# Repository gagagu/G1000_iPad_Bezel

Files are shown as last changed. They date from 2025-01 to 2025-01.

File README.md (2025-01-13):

# G1000_iPad_Bezel
G1000 iPad Bezel for Simionic &amp; Mobiflight

This is my DIY Garmin G100 Bezel made for using with my iPad. You can use it with the Simionic G1000 App or with Mobiflight and something like Spacedesk. It's not finished but working.
The ESP is used for emulating an bluetooth keyboard for controling the Simionic App. The Arduino is controlling the Encoders, Buttons and the ESP32. You can also remove the ESP32 and use the G1000 only with Mobiflight and an Screen App like Spacedesk.
The Bezel is 3d printed with an Prusa XL 

##I had some power issues with my design so i had to implement an level converter and split the power lines from ESP32, Arduino and the other electronics. This is not implemented in the Schematic and PCB, yet.

## The design has some issues but with some knowledge in electronics you could get it to work. This is nothing for a beginner in electronics!

# Additional Files:

G1000 Pan Zoom switch by FlightSimMaker on Thingiverse: 
(https://www.thingiverse.com/thing:4222606

G1000 Knobs and Dual Rotary Encoder by FlightSimMaker on Thingiverse: 
(https://www.thingiverse.com/thing:4373531]

## Discord
You are welcome to join my Discord to get Info and support, [here](https://discord.gg/zrYUcJWu7F)

# Gallery

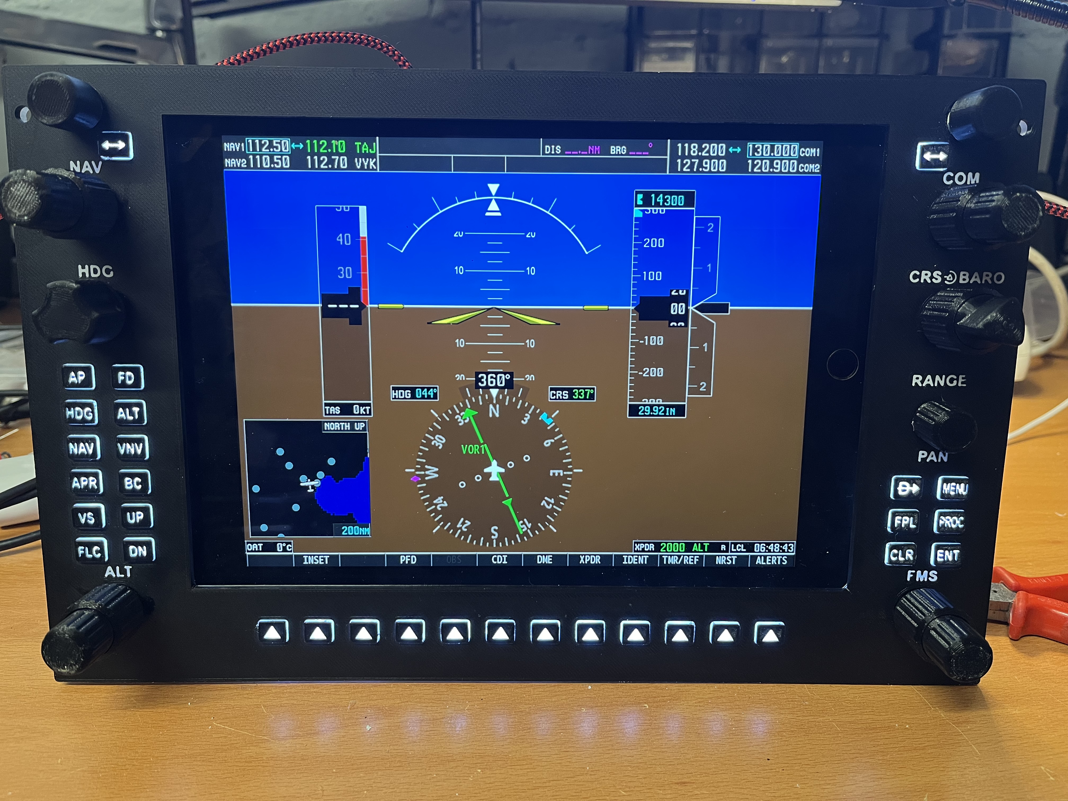
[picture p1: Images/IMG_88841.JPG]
[](https://github.com/gagagu/G1000_iPad_Bezel/blob/main/Images/IMG_88841.JPG)
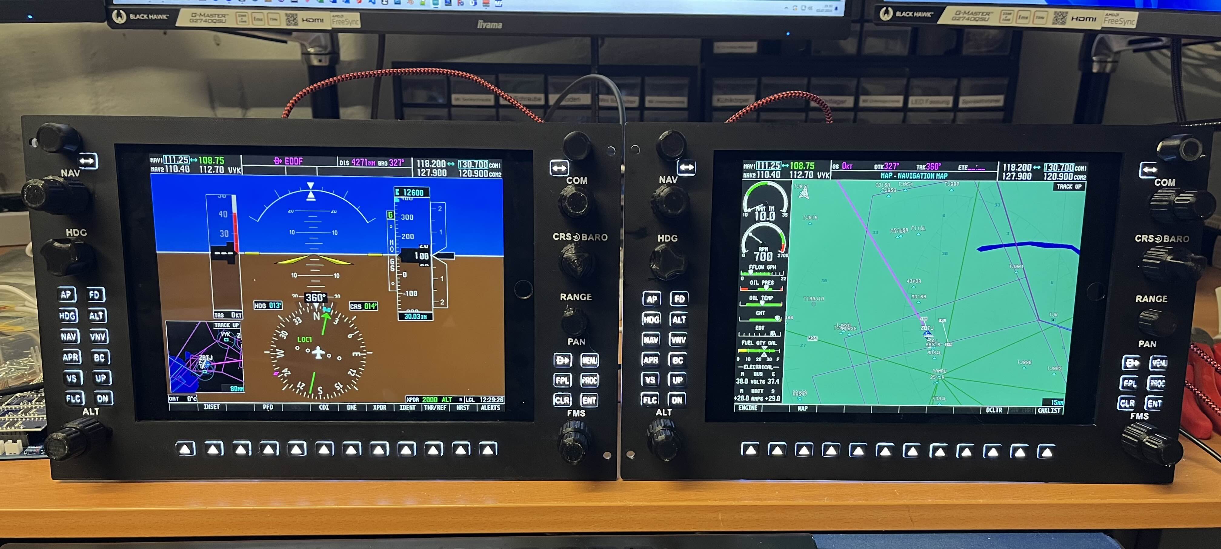
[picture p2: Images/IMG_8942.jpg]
[](https://github.com/gagagu/G1000_iPad_Bezel/blob/main/Images/IMG_8942.jpg)
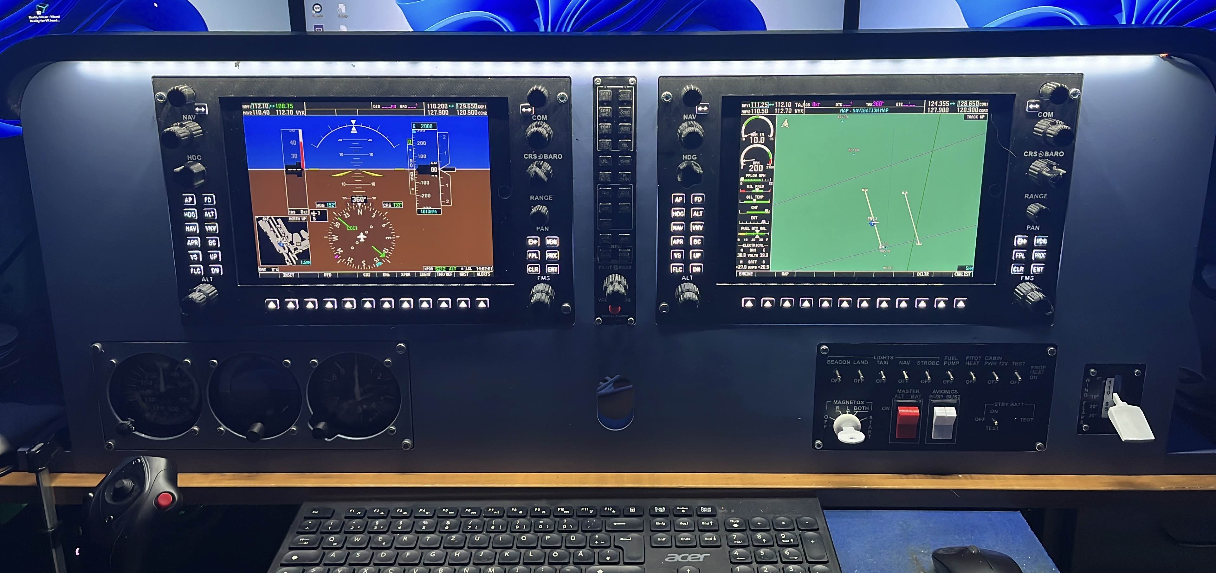
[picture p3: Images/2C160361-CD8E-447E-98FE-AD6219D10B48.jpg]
[](https://github.com/gagagu/G1000_iPad_Bezel/blob/main/Images/2C160361-CD8E-447E-98FE-AD6219D10B48.jpg)
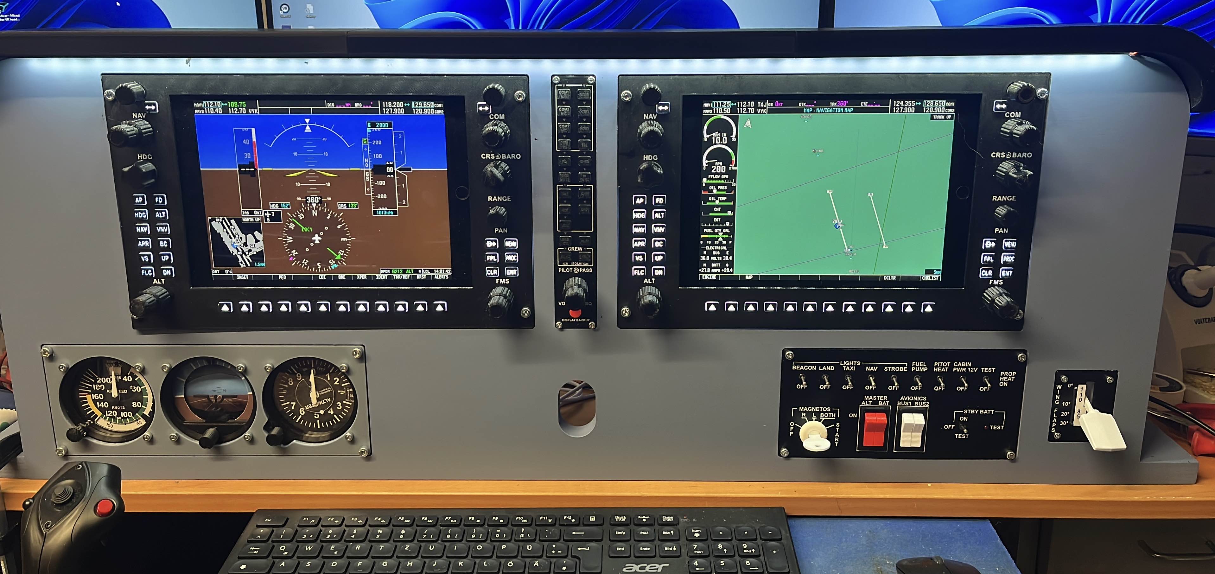
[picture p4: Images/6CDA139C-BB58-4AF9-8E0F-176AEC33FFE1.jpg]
[](https://github.com/gagagu/G1000_iPad_Bezel/blob/main/Images/6CDA139C-BB58-4AF9-8E0F-176AEC33FFE1.jpg)
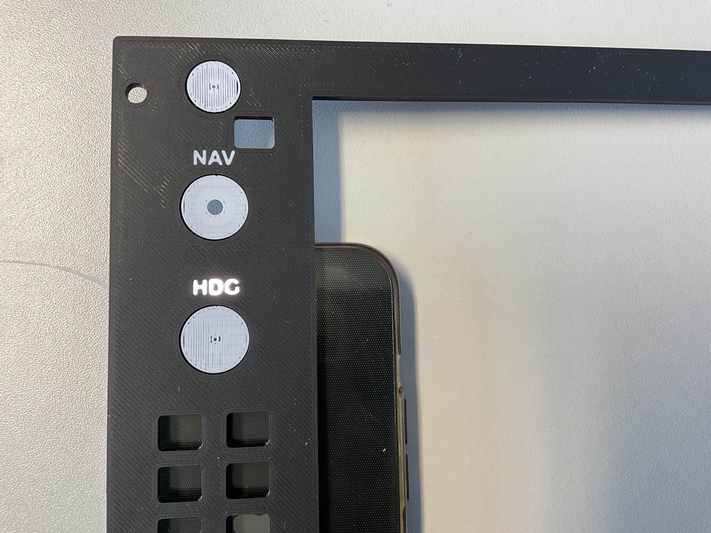
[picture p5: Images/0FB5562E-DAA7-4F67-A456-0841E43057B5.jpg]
[](https://github.com/gagagu/G1000_iPad_Bezel/blob/main/Images/0FB5562E-DAA7-4F67-A456-0841E43057B5.jpg)
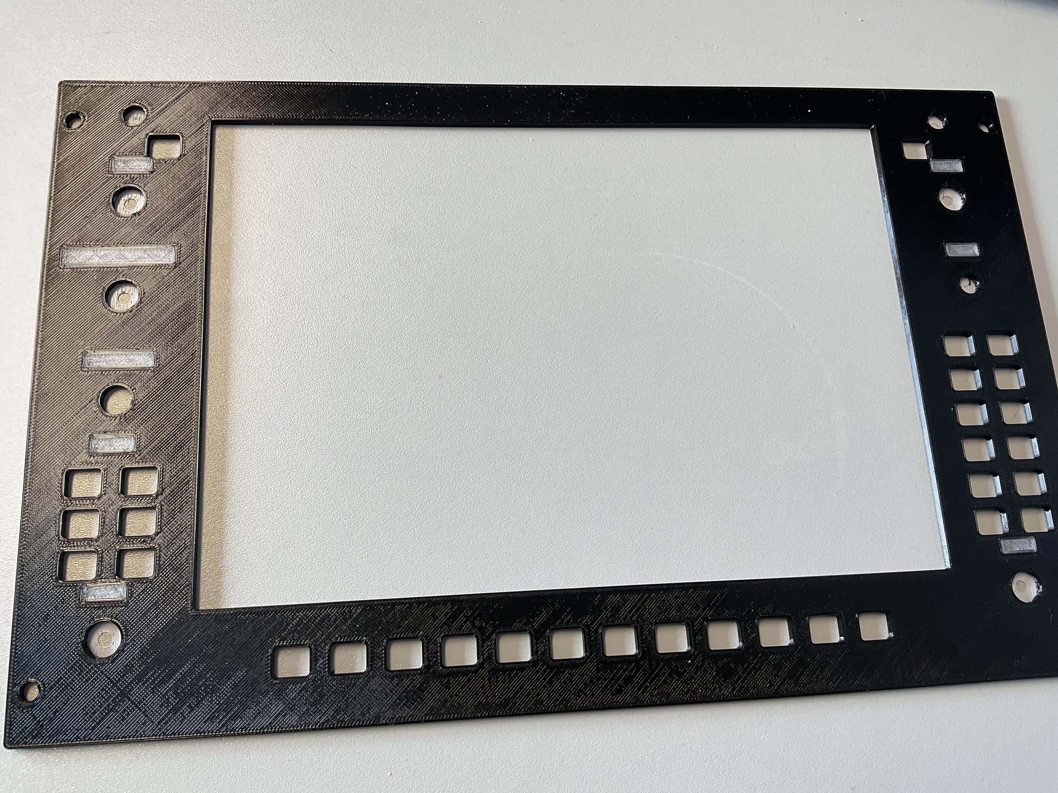
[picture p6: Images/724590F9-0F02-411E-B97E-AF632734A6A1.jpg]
[](https://github.com/gagagu/G1000_iPad_Bezel/blob/main/Images/724590F9-0F02-411E-B97E-AF632734A6A1.jpg)
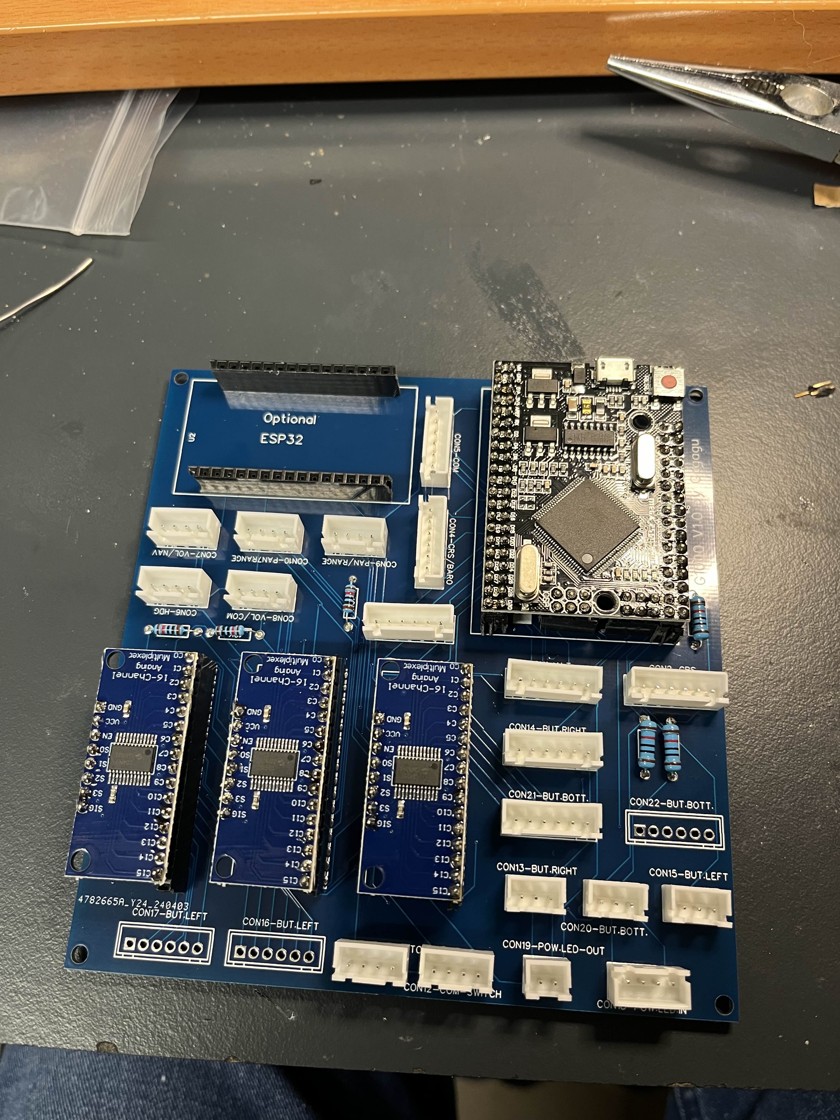
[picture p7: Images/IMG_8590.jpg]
[](https://github.com/gagagu/G1000_iPad_Bezel/blob/main/Images/IMG_8590.jpg)
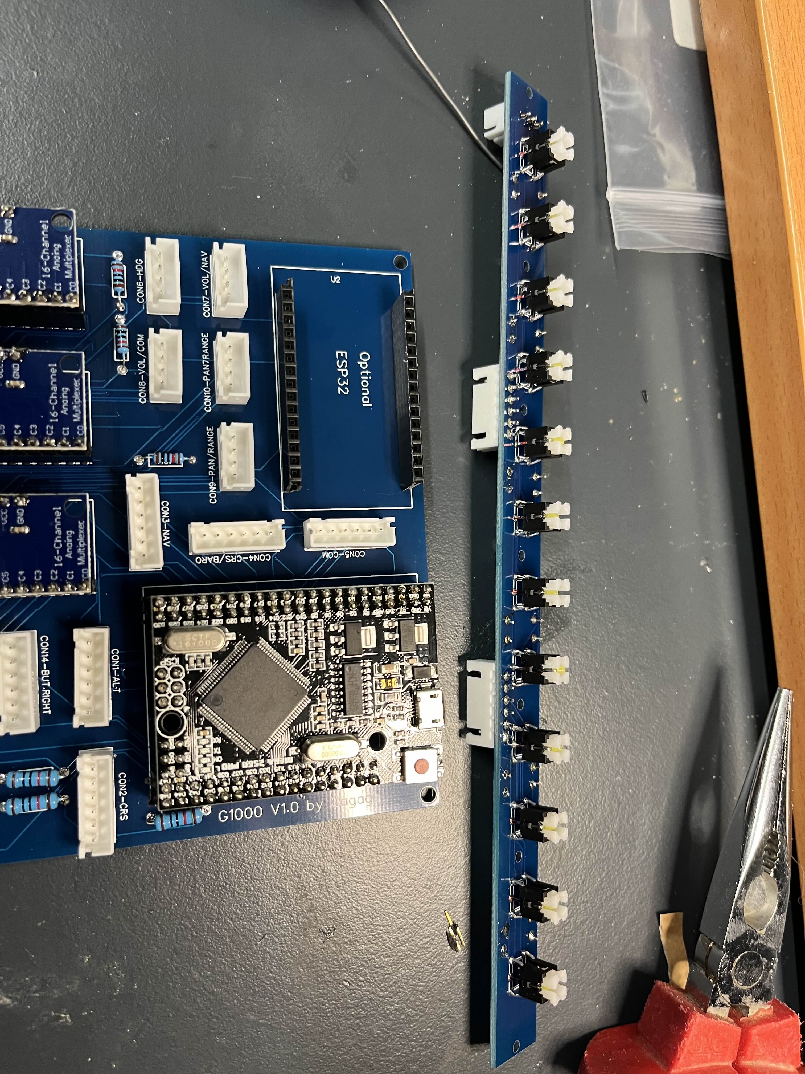
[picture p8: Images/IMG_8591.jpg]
[](https://github.com/gagagu/G1000_iPad_Bezel/blob/main/Images/IMG_8591.jpg)
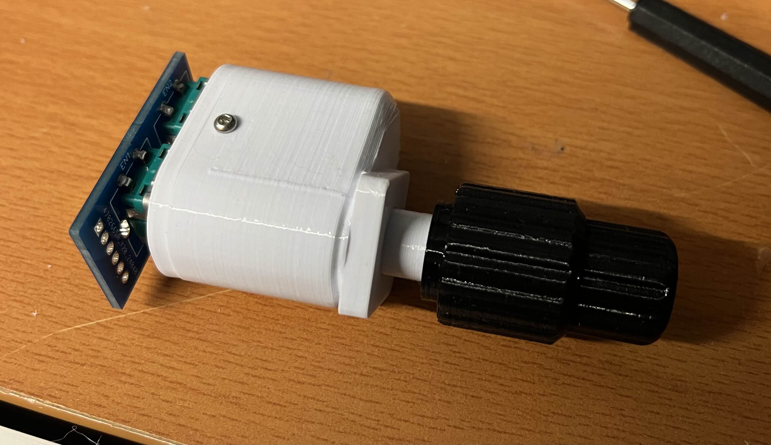
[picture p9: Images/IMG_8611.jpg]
[](https://github.com/gagagu/G1000_iPad_Bezel/blob/main/Images/IMG_8611.jpg)
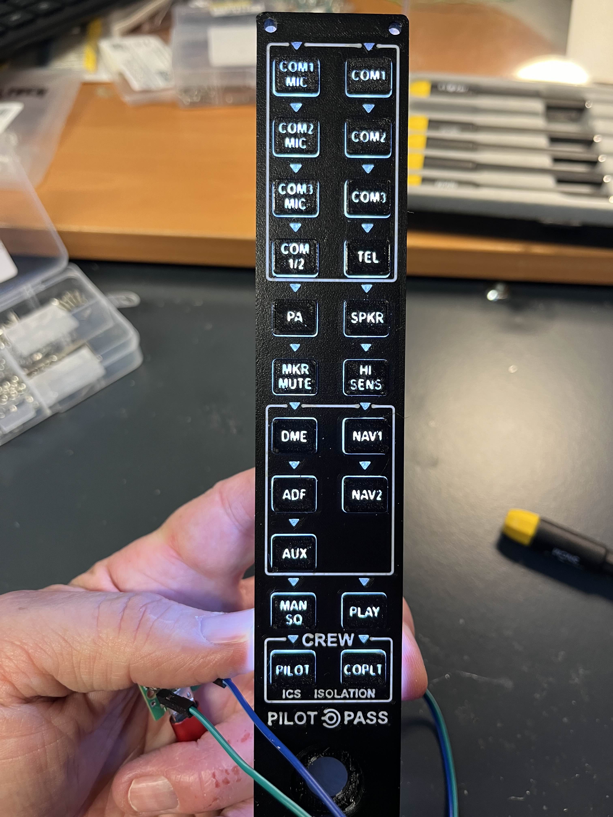
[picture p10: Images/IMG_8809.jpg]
[](https://github.com/gagagu/G1000_iPad_Bezel/blob/main/Images/IMG_8809.jpg)
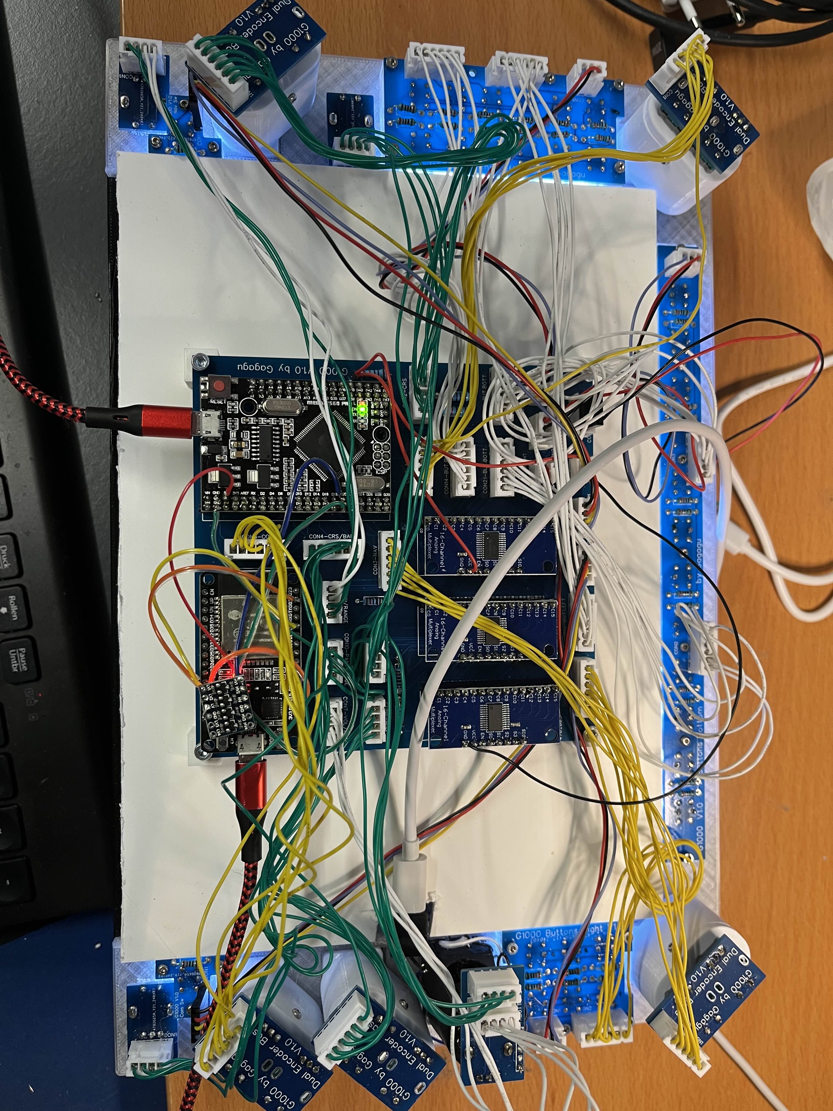
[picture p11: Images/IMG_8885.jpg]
[](https://github.com/gagagu/G1000_iPad_Bezel/blob/main/Images/IMG_8885.jpg)
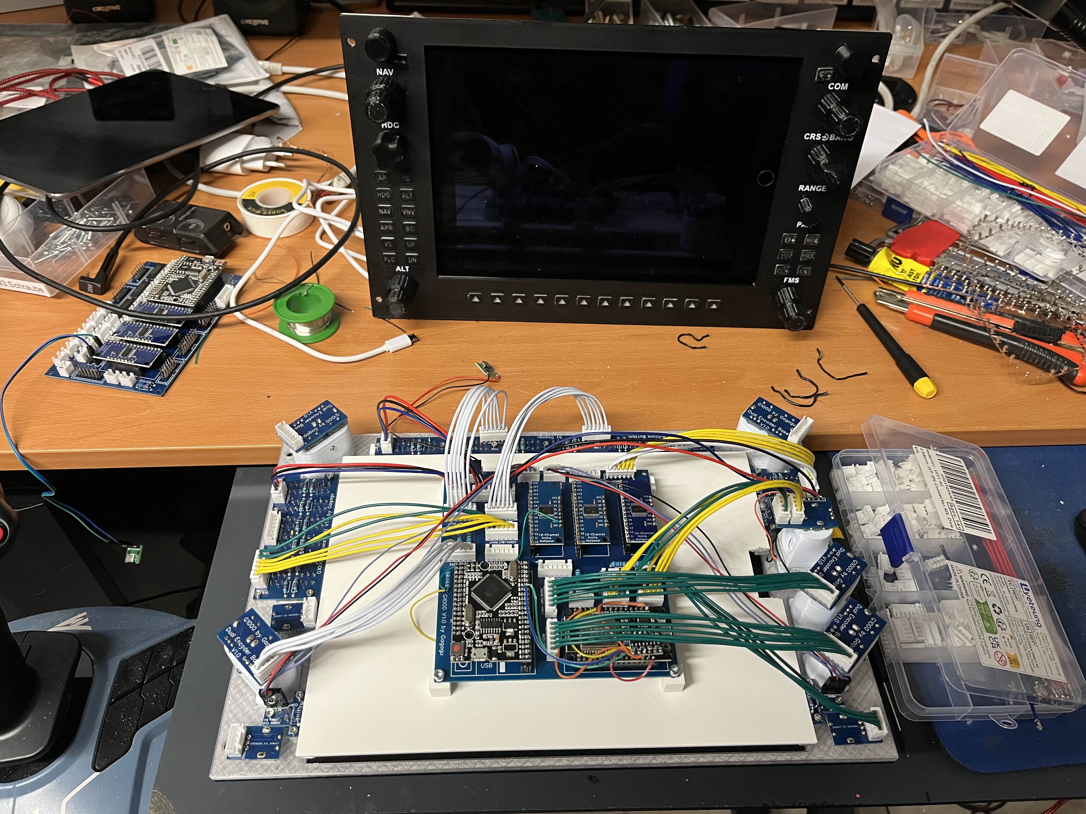
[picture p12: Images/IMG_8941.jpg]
[](https://github.com/gagagu/G1000_iPad_Bezel/blob/main/Images/IMG_8941.jpg)

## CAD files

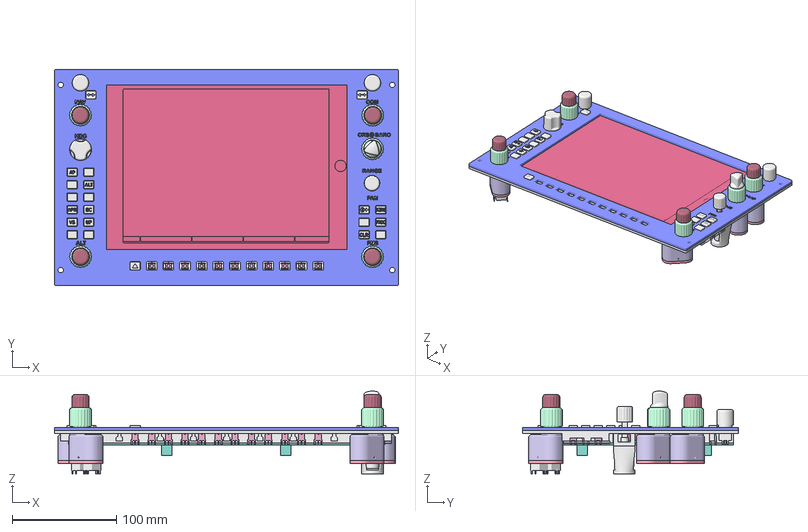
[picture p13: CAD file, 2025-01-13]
Freecad/G1000-11.FCStd
330.7 x 208.0 x 79.7 mm
Körper003
iPad10.9
HousingV003
Inner_Shaft_6mm_Round-3mm001
Outer_Shaftv004
Rotary_Gear_6mm_Round001
Duel_Outer001
Duel_Inner001
LidV4_recessed_encoders_inside001
HousingV004
Inner_Shaft_6mm_Round-3mm002
Outer_Shaftv005
Rotary_Gear_6mm_Round002
Duel_Outer002
Duel_Inner002
LidV4_recessed_encoders_inside002
HDG001
HousingV005
Inner_Shaft_6mm_Round-3mm003
Outer_Shaftv006
Rotary_Gear_6mm_Round003
Duel_Outer003
Duel_Inner003
LidV4_recessed_encoders_inside003
HousingV006
Inner_Shaft_6mm_Round-3mm004
Outer_Shaftv007
Rotary_Gear_6mm_Round004
Duel_Outer004
Duel_Inner004
LidV4_recessed_encoders_inside004
HousingV007
Inner_Shaft_6mm_Round-3mm005
Outer_Shaftv008
Rotary_Gear_6mm_Round005
Duel_Outer005
LidV4_recessed_encoders_inside005
Duel_Inner_CRS001
Volume001
Volume002
HousingV4
PCB
TactHousing
knob
knobshaft
ShaftV2
PinV2
PinV003
PinV004
PinV005
Encoder_Connector_V5

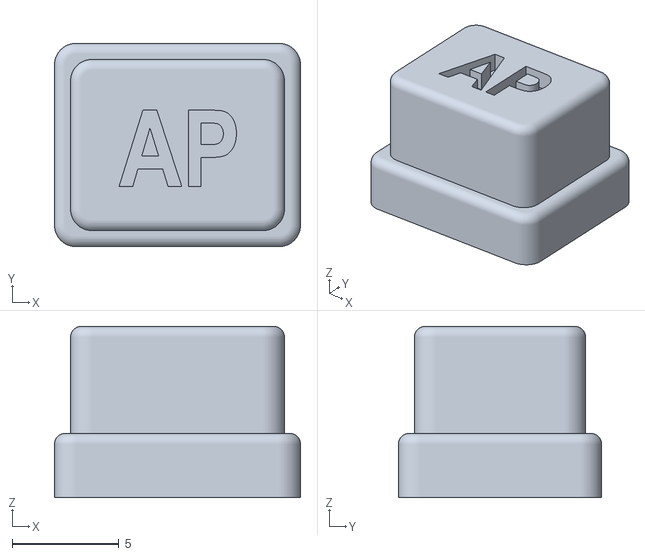
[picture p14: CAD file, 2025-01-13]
Stl/Buttons/G1000-07-ButtonsButton_AP.stl
11.5 x 9.50 x 8.00

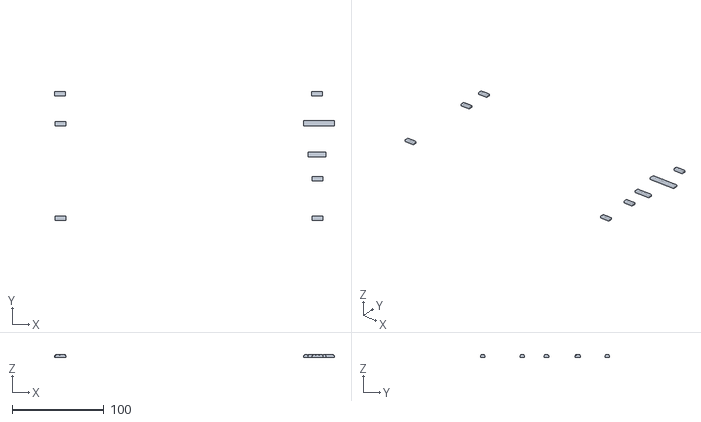
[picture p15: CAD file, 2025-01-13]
Stl/G1000-08-BezelTop_V002_Inside.obj
305.6 x 140.6 x 2.80

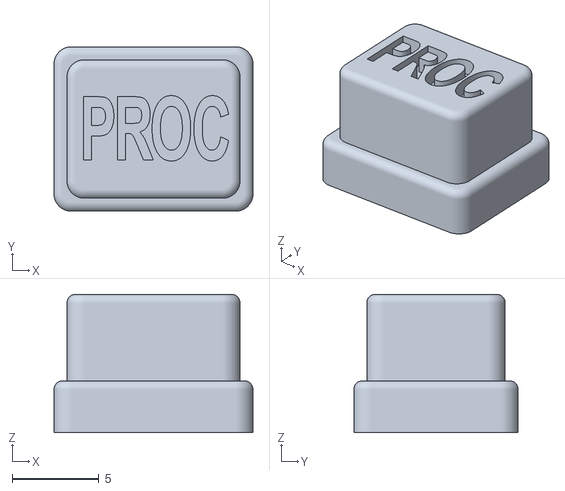
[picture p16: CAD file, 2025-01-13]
Stl/Buttons/G1000-07-ButtonsButton_PROC.stl
11.5 x 9.50 x 8.00

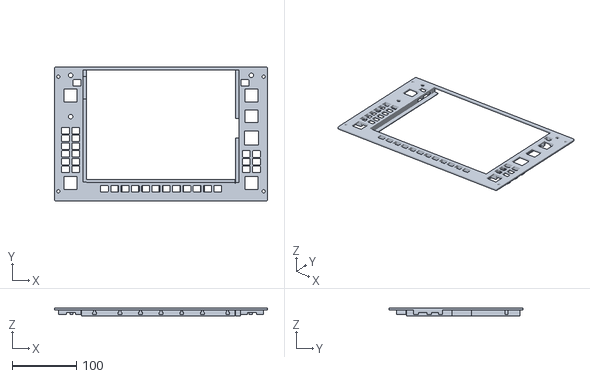
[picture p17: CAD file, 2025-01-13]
Stl/G1000-BezelBottom.stl
330.7 x 208.0 x 12.1

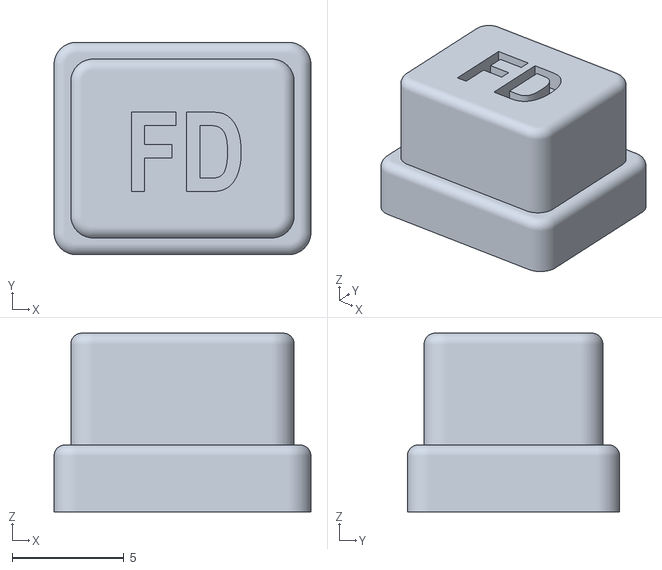
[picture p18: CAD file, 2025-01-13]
Stl/Buttons/G1000-07-ButtonsButton_FD.stl
11.5 x 9.50 x 8.00

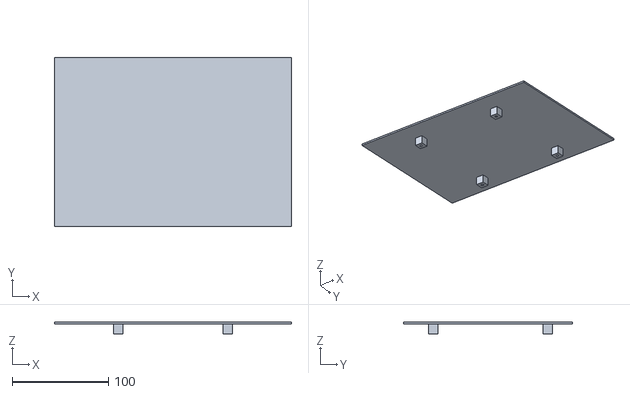
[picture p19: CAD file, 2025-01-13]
Stl/G1000-Bezel-iPad-Holder-Plate.stl
246.7 x 176.0 x 12.0

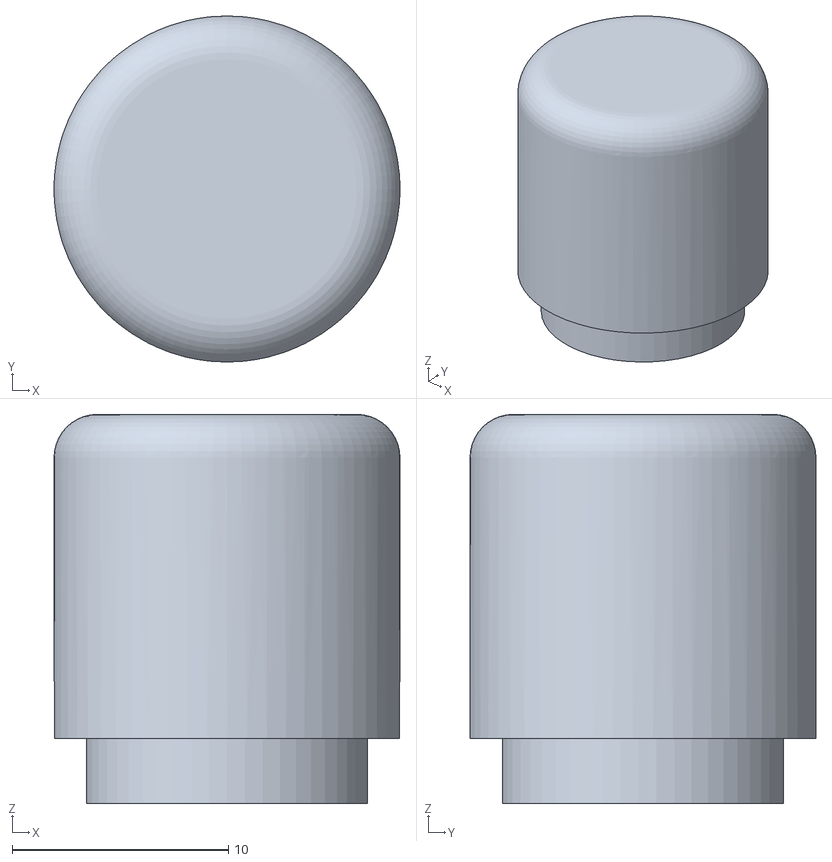
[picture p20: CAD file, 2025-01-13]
Stl/Volume.stl
16.0 x 16.0 x 18.0

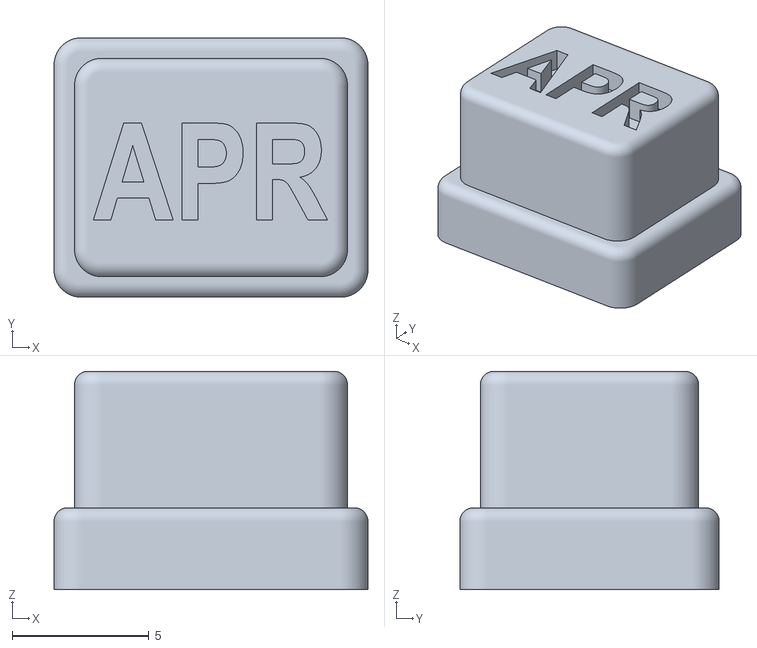
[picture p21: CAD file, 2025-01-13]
Stl/Buttons/G1000-07-ButtonsButton_APR.stl
11.5 x 9.50 x 8.00

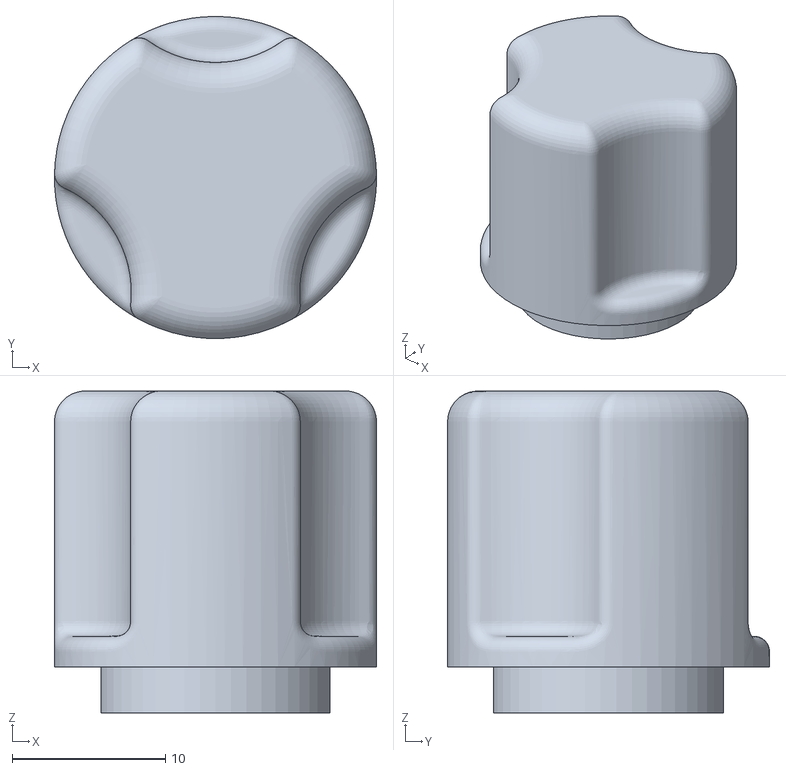
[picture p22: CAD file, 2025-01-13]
Stl/Knob_HDG.stl
21.0 x 21.0 x 21.0

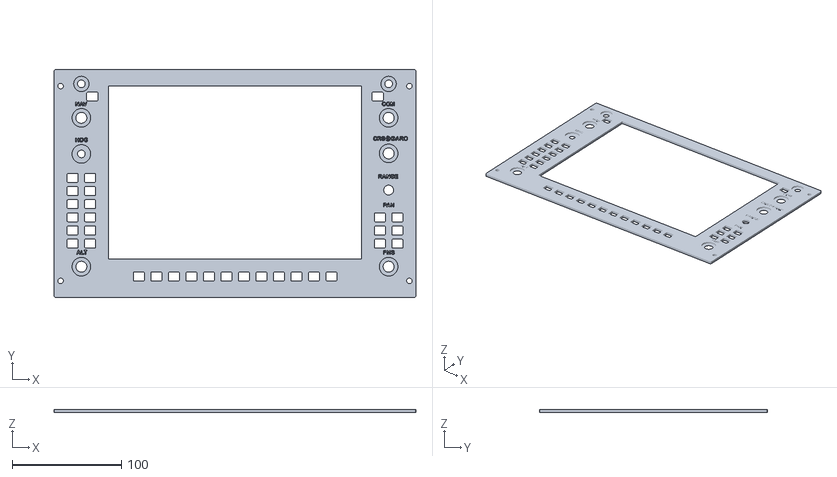
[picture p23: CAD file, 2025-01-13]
Stl/G1000-08-BezelTop_V002.obj
330.7 x 208.0 x 3.00

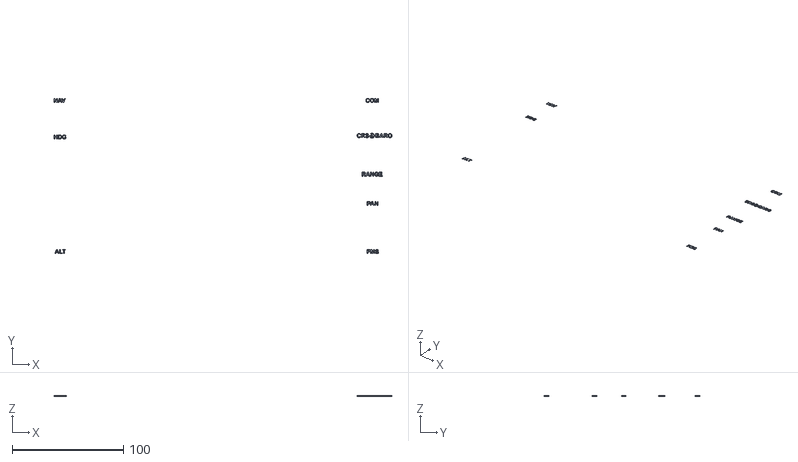
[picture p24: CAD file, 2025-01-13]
Stl/G1000-08-BezelTop_V002_Text.obj
303.3 x 139.5 x 0.2

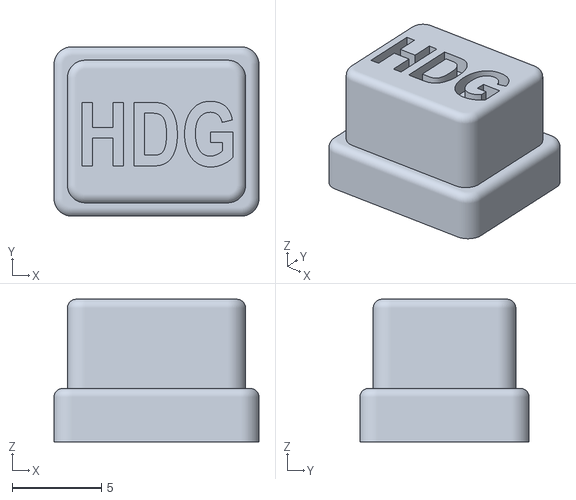
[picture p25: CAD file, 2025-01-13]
Stl/Buttons/G1000-07-ButtonsButton_HDG.stl
11.5 x 9.50 x 8.00

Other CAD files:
Stl/Buttons/G1000-07-ButtonsButton_FlipFlop.stl
Stl/Buttons/G1000-07-ButtonsButton_VS.stl
Stl/Buttons/G1000-07-ButtonsButton_BC.stl
Stl/Buttons/G1000-07-ButtonsButton_FLC.stl
Stl/Buttons/G1000-07-ButtonsButton_NAV.stl
Stl/Buttons/G1000-07-ButtonsButton_ALT.stl
Stl/Buttons/G1000-07-ButtonsButton_CLR.stl
Stl/Buttons/G1000-07-ButtonsButton_DCT.stl
Stl/Buttons/G1000-07-ButtonsButton_DN.stl
Stl/Buttons/G1000-07-ButtonsButton_ENT.stl
Stl/Buttons/G1000-07-ButtonsButton_FPL.stl
Stl/Buttons/G1000-07-ButtonsButton_MENU.stl
Stl/Buttons/G1000-07-ButtonsButton_Triangle.stl
Stl/Buttons/G1000-07-ButtonsButton_UP.stl
Stl/Buttons/G1000-07-ButtonsButton_VNV.stl

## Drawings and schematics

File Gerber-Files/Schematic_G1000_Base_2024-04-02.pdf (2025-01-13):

A | A
B | B

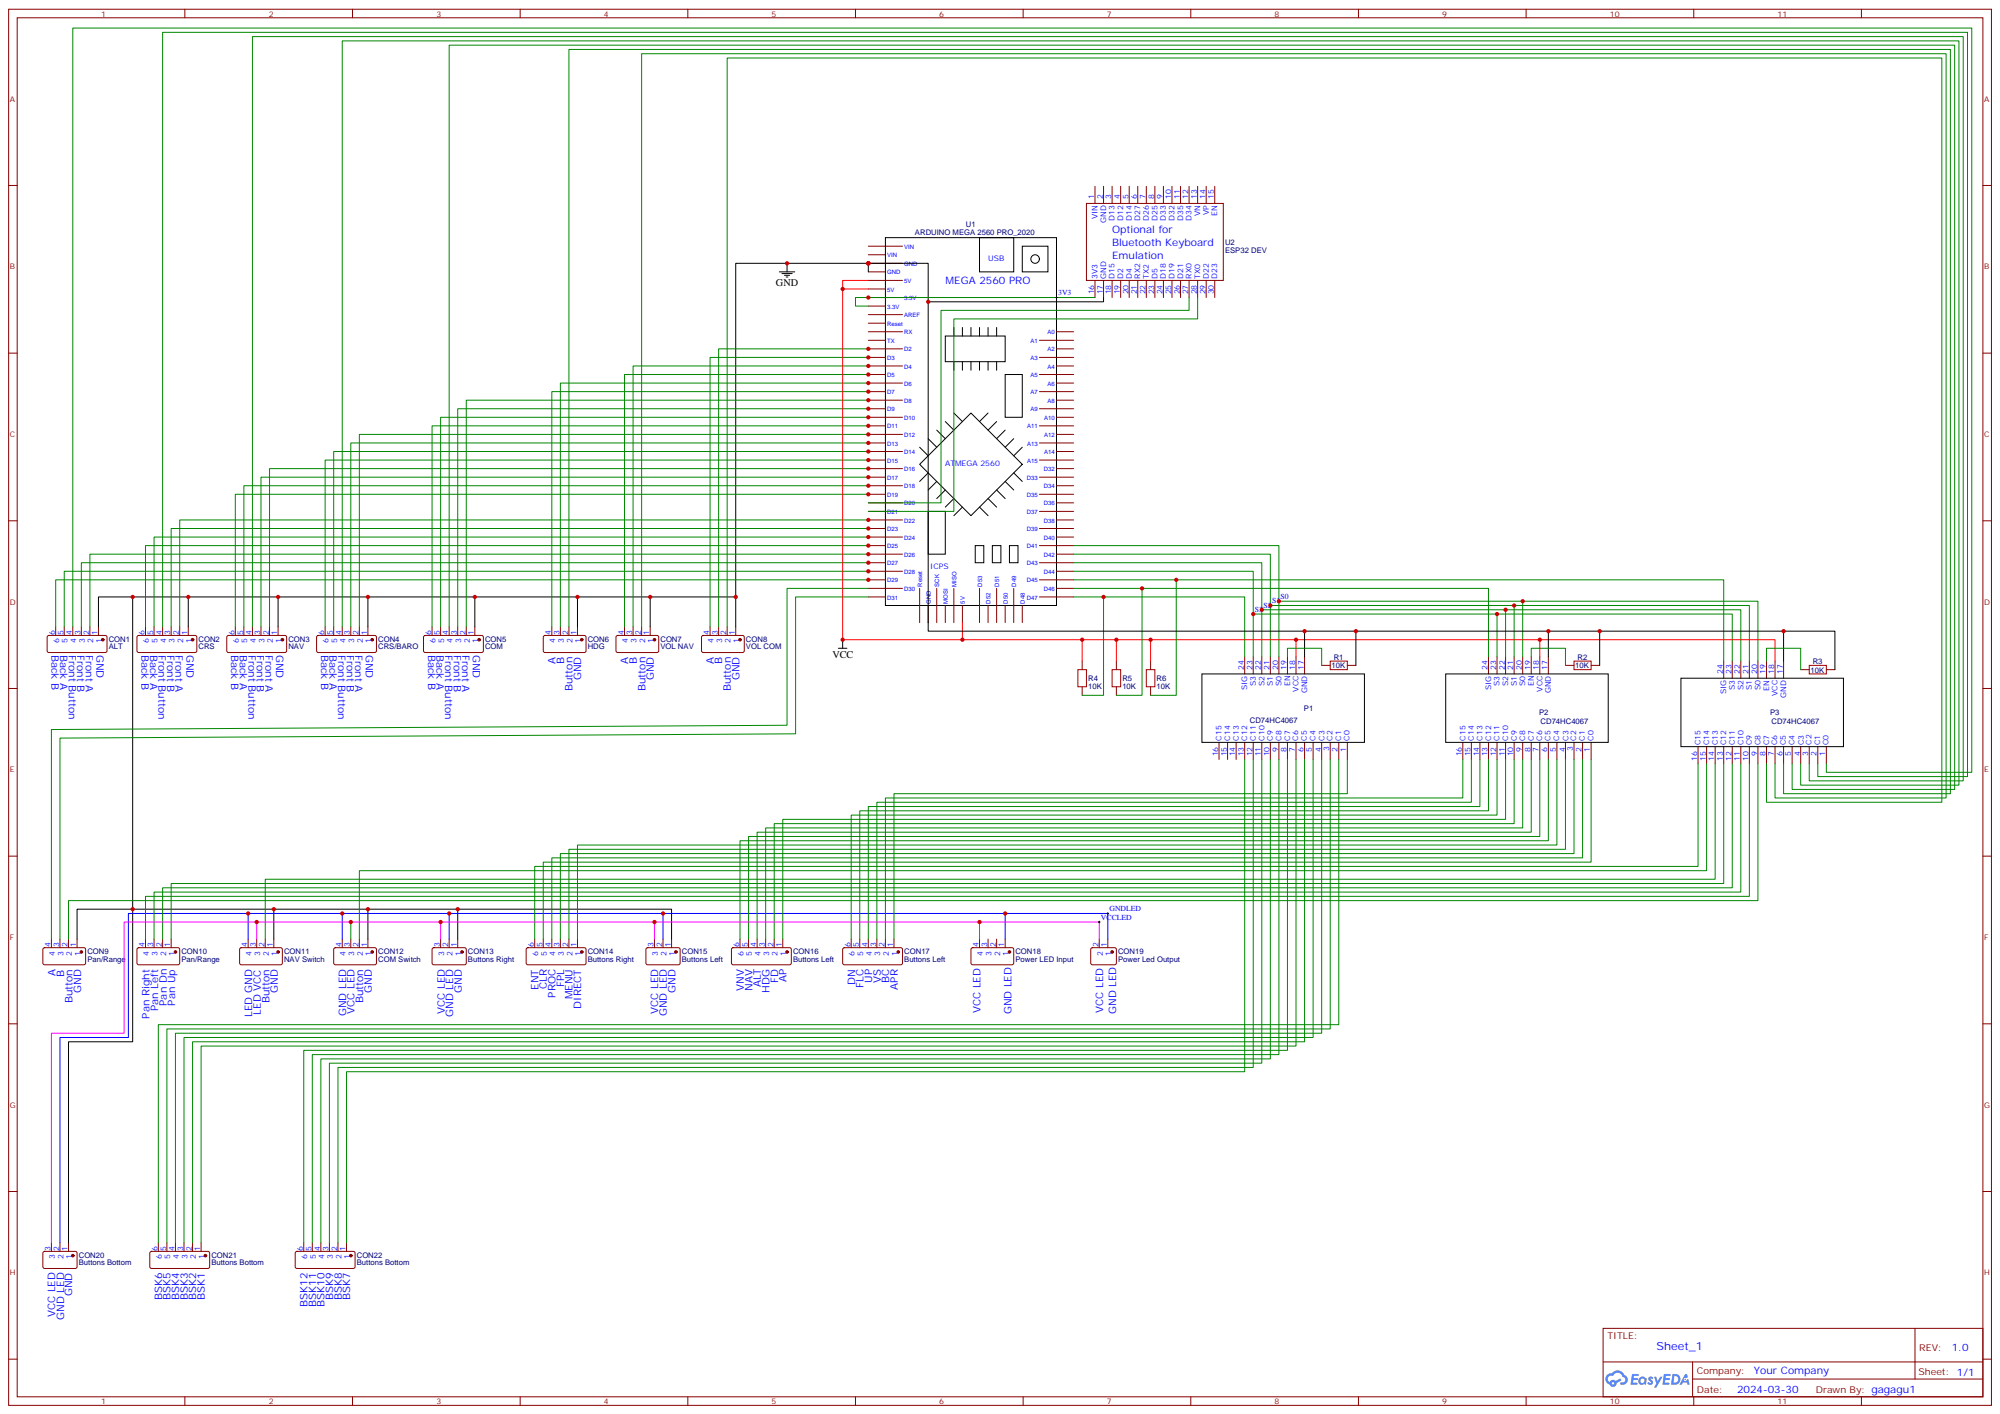
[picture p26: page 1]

GND 17 VCC 18 EN 19 S0 20 S1 21 S2 22 S3 23 SIG 24

Pan Right Pan Left

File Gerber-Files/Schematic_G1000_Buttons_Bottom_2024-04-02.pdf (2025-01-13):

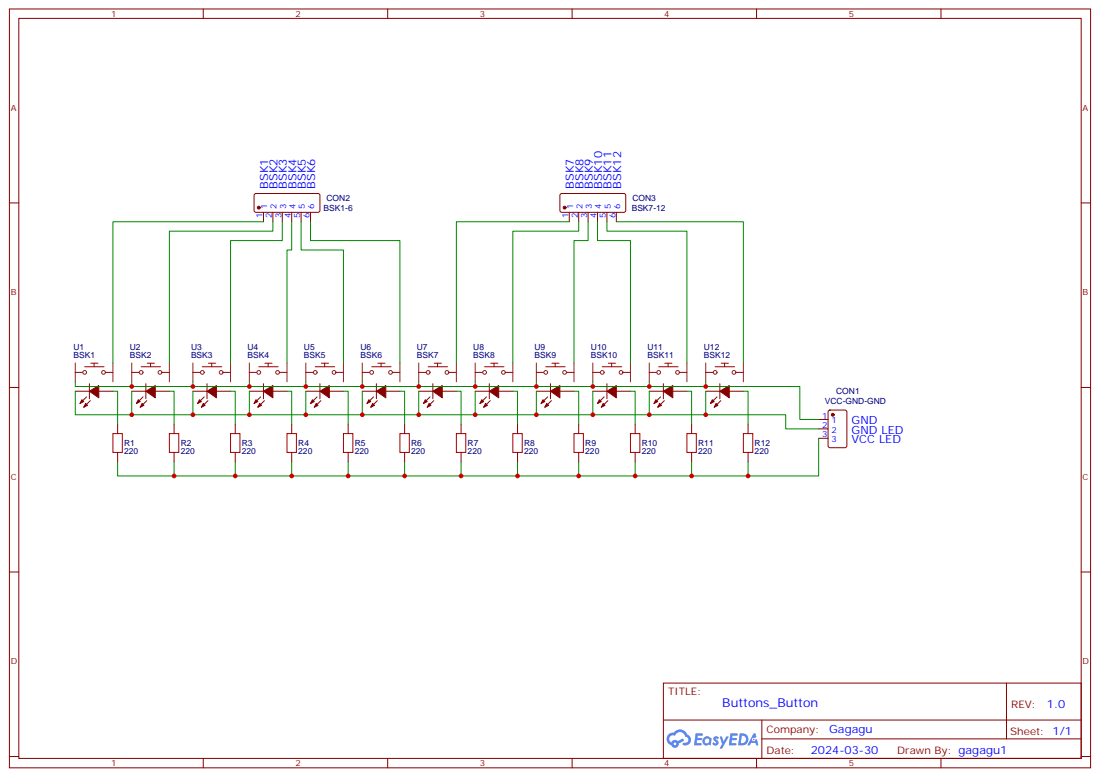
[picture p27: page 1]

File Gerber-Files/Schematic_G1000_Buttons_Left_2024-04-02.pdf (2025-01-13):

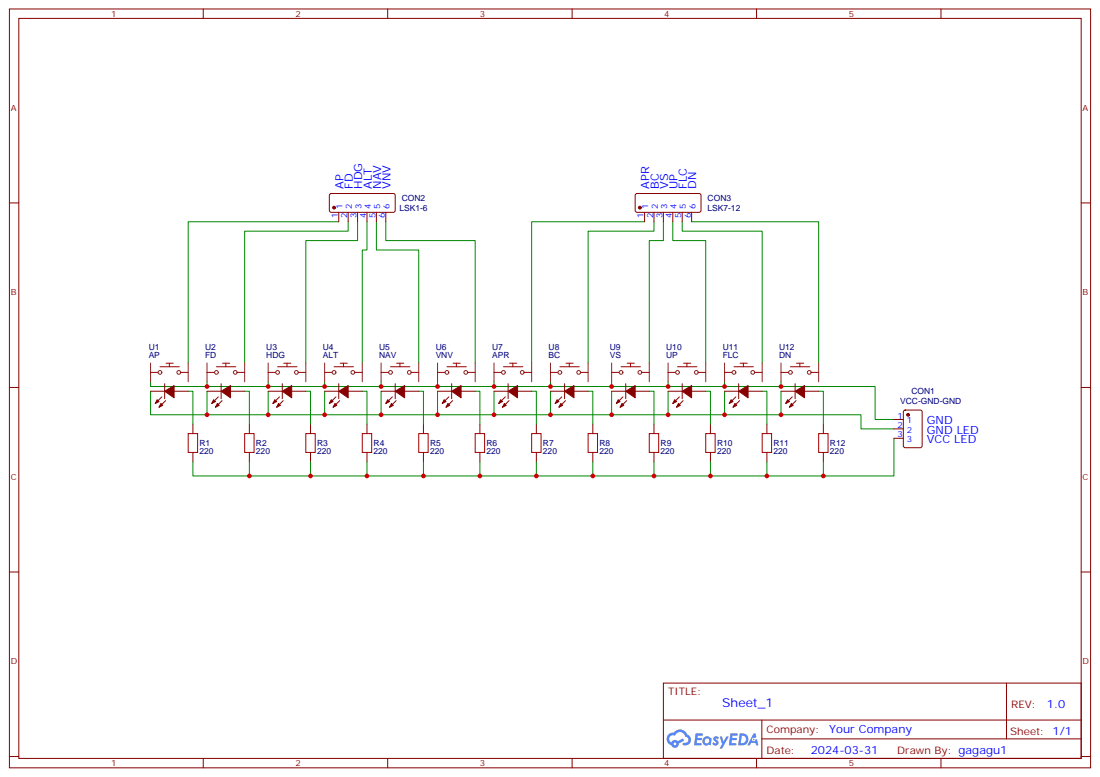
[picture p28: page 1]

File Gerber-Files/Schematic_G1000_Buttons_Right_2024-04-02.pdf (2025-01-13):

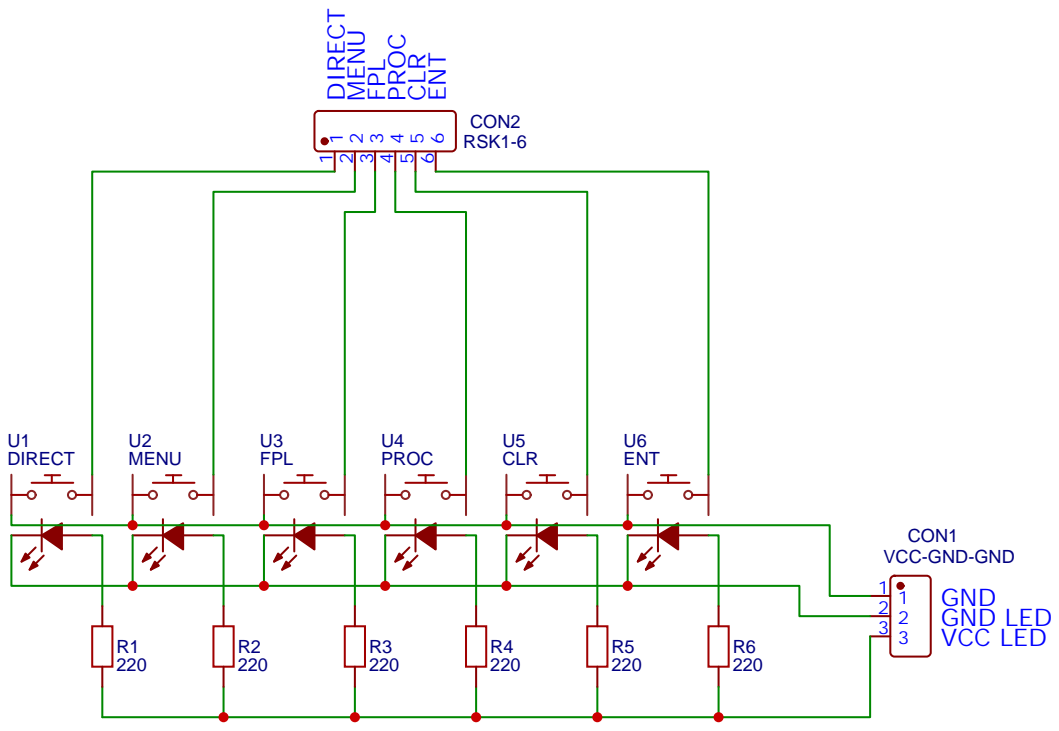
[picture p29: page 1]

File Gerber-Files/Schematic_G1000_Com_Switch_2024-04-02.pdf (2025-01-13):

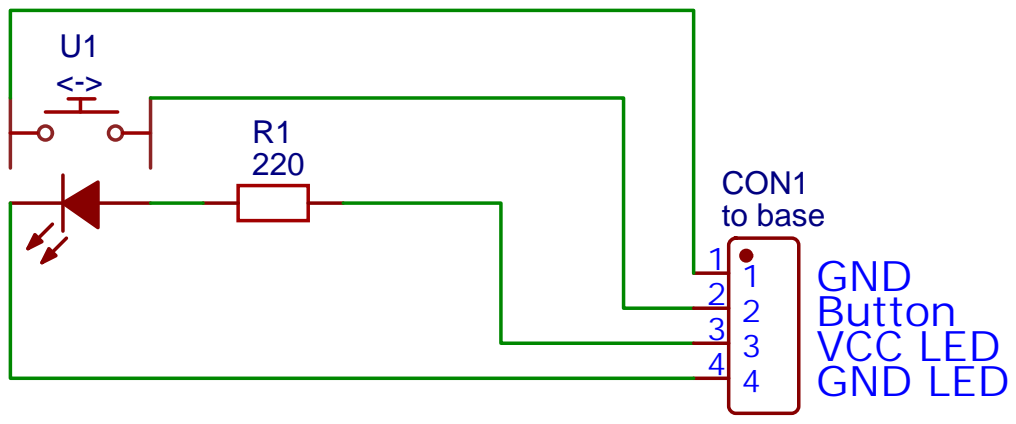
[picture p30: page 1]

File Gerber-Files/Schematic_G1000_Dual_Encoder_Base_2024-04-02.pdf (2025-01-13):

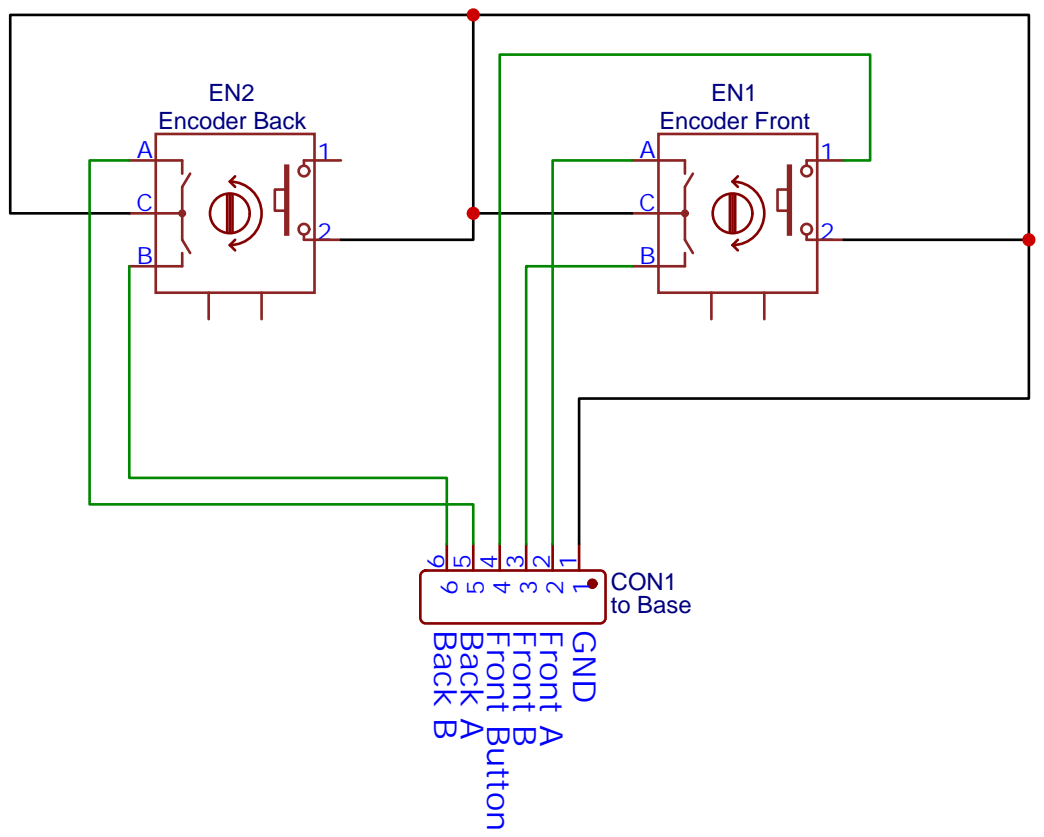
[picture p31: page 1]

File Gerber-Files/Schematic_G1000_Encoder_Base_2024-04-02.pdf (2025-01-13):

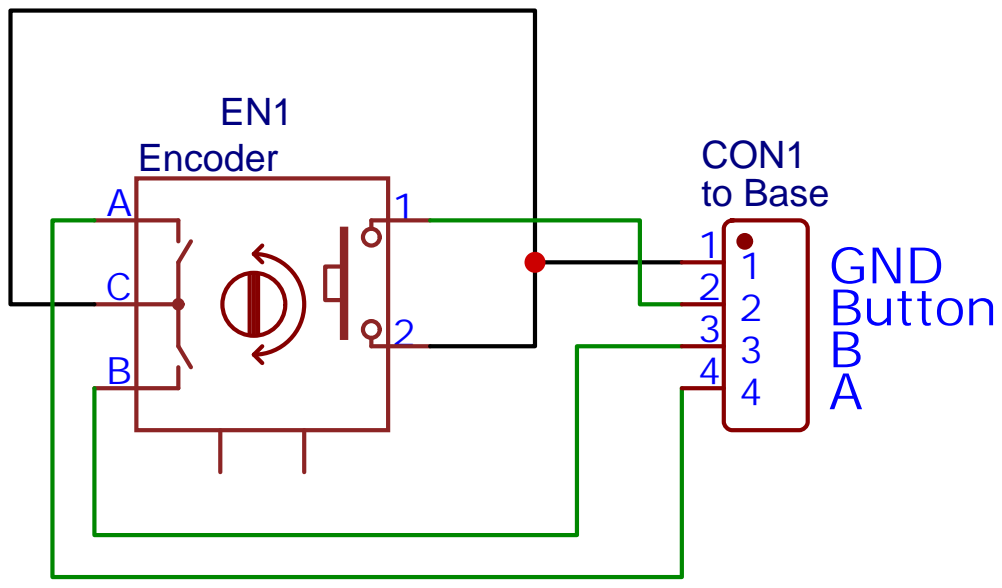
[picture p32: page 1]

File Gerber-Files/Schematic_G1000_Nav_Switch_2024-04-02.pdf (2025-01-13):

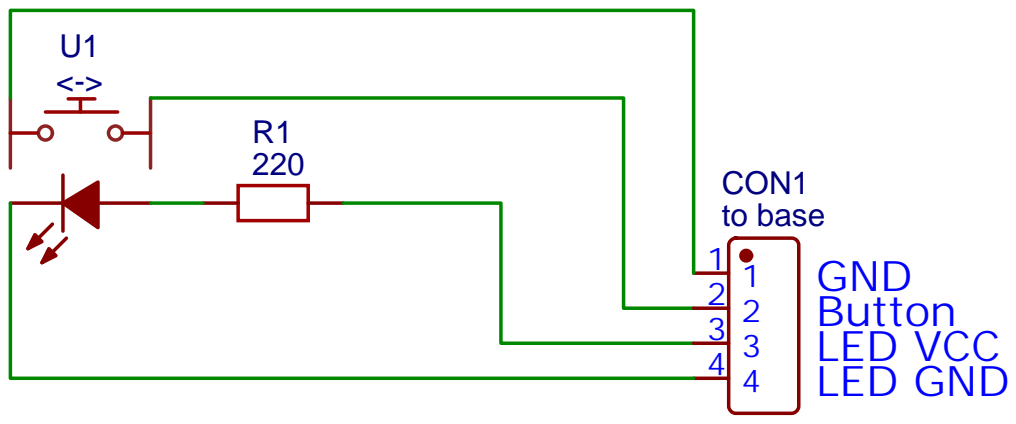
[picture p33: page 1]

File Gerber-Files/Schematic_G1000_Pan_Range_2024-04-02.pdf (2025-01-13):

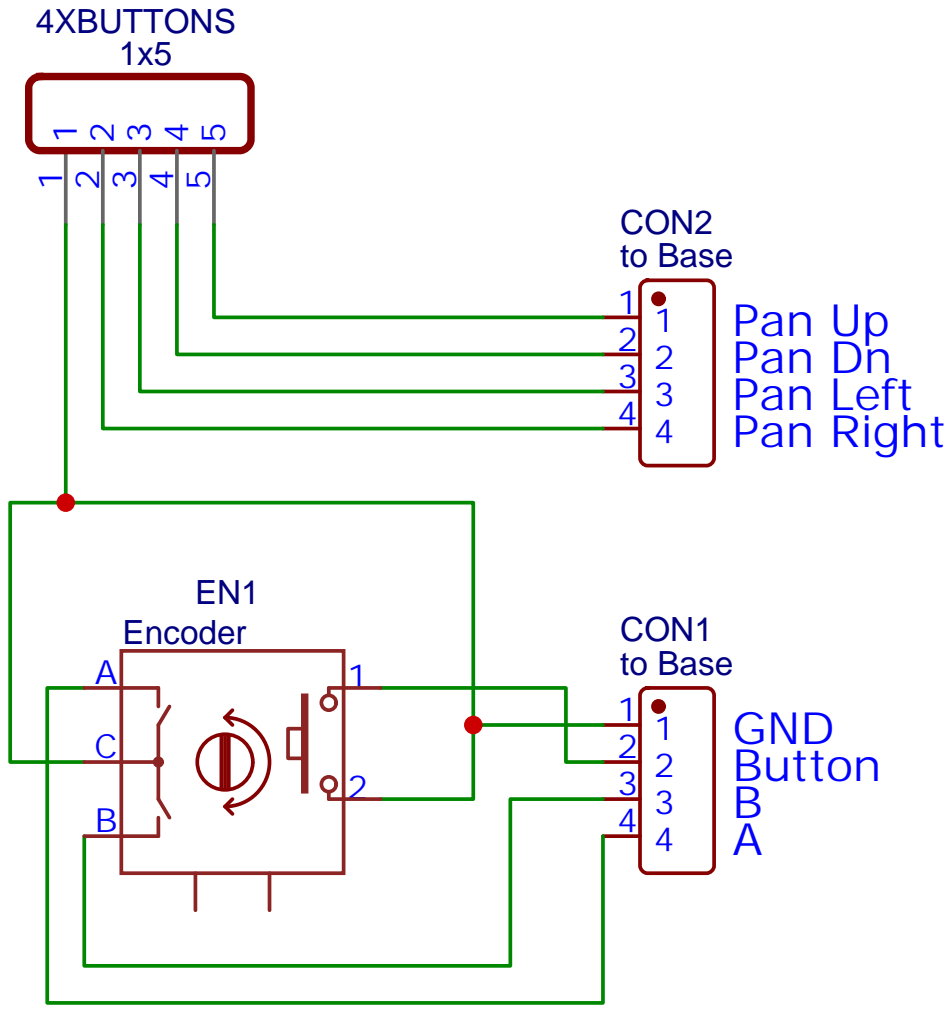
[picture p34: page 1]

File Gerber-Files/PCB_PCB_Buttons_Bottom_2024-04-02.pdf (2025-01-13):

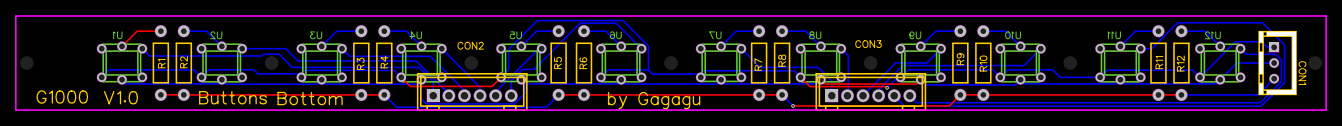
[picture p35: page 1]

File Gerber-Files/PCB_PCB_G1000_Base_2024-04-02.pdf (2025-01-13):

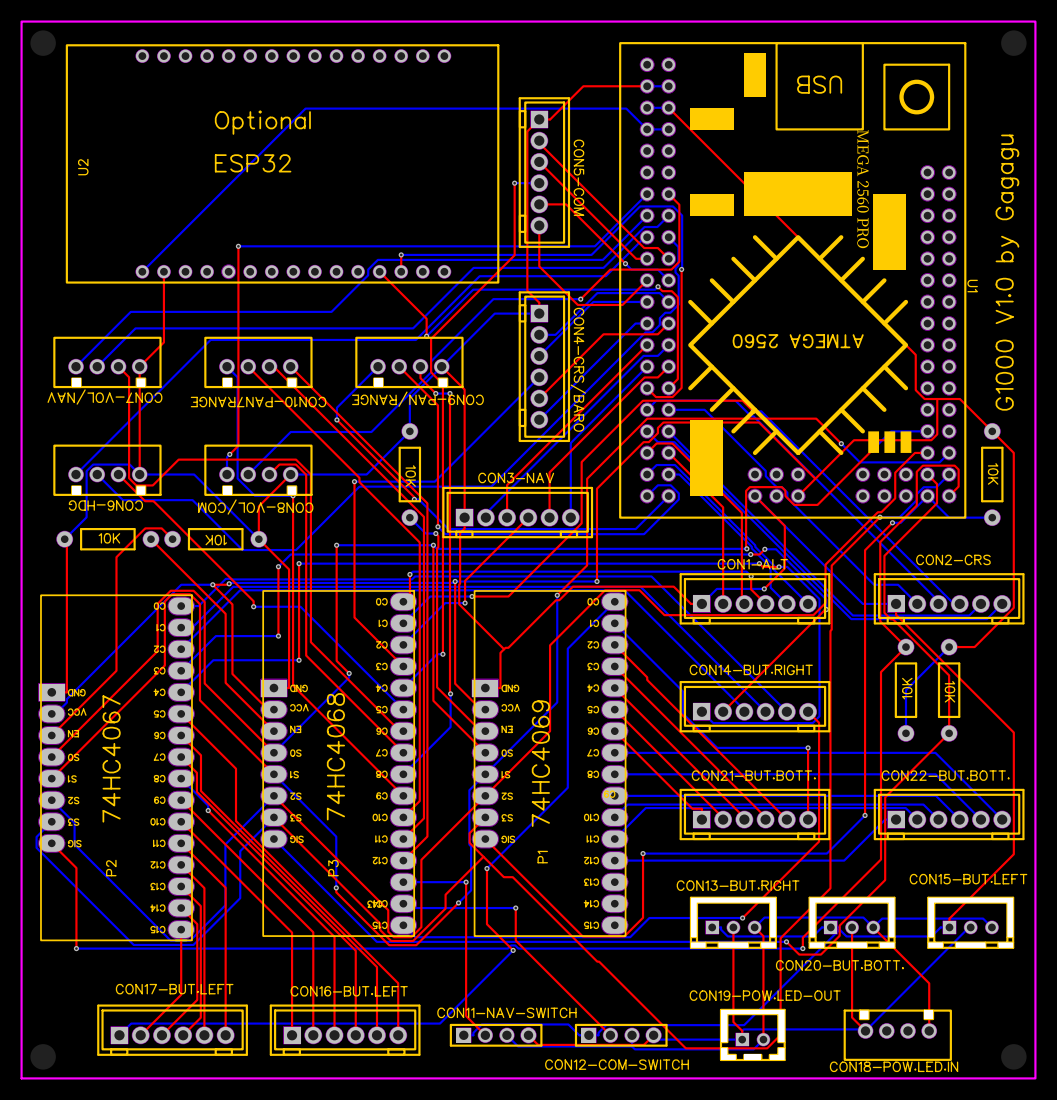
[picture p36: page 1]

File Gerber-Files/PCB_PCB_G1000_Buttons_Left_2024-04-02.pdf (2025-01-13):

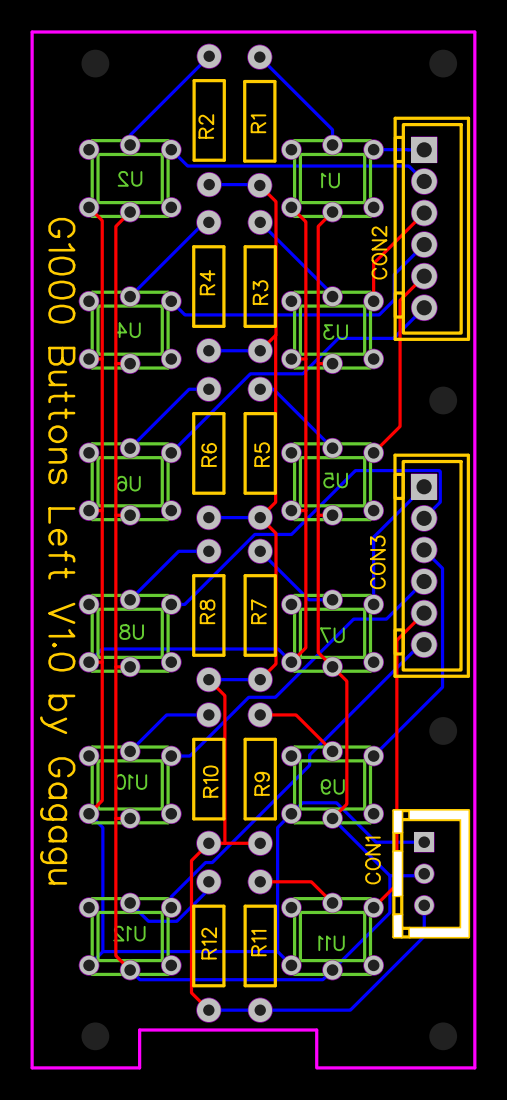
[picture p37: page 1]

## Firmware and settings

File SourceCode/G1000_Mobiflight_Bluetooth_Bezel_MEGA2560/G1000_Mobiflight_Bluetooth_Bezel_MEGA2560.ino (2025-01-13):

/*

  G1000 Bezel for Simionic iOS App by A.Eckers aka Gagagu
  See more info on www.gagagu.de

*/

/******************** Created by A. Eckers ************************/
#include <Wire.h>
#include <Encoder.h>
#include <light_CD74HC4067.h>

//#define DEBUG
#define NODEBUG  

/************************** PINS *********************************/
#define ENCODER_HDG_A 3
#define ENCODER_HDG_B 2

#define ENCODER_RANGE_A 4
#define ENCODER_RANGE_B 5

#define ENCODER_VOL_COM_A 6
#define ENCODER_VOL_COM_B 7

#define ENCODER_COM_FRONT_A 9
#define ENCODER_COM_FRONT_B 8
#define ENCODER_COM_BACK_A 10
#define ENCODER_COM_BACK_B 11

#define ENCODER_CRS_FRONT_A 13
#define ENCODER_CRS_FRONT_B 12
#define ENCODER_CRS_BACK_A 14
#define ENCODER_CRS_BACK_B 15

#define ENCODER_FMS_FRONT_A 17
#define ENCODER_FMS_FRONT_B 16
#define ENCODER_FMS_BACK_A 18
#define ENCODER_FMS_BACK_B 19

#define ENCODER_NAV_FRONT_A 23
#define ENCODER_NAV_FRONT_B 22
#define ENCODER_NAV_BACK_A 24
#define ENCODER_NAV_BACK_B 25

#define ENCODER_ALT_FRONT_A 27
#define ENCODER_ALT_FRONT_B 26
#define ENCODER_ALT_BACK_A 28
#define ENCODER_ALT_BACK_B 29

#define ENCODER_VOL_NAV_A 30
#define ENCODER_VOL_NAV_B 31

#define MUX_S0 41
#define MUX_S1 42
#define MUX_S2 43
#define MUX_S3 44

#define MUX1_INPUT 47
#define MUX2_INPUT 46
#define MUX3_INPUT 45

// I2C Values for ESP control
#define ENCODER_ALT_FRONT_UP "56"
#define ENCODER_ALT_FRONT_DN "57"
#define ENCODER_ALT_BACK_UP "54"
#define ENCODER_ALT_BACK_DN "55"
#define ENCODER_HDG_UP "51"
#define ENCODER_HDG_DN "52"

#define ENCODER_NAV_FRONT_UP "48"
#define ENCODER_NAV_FRONT_DN "49"
#define ENCODER_NAV_BACK_UP "46"
#define ENCODER_NAV_BACK_DN "47"
#define ENCODER_VOL_NAV_UP "42"
#define ENCODER_VOL_NAV_DN "43"
#define ENCODER_RANGE_UP "35"
#define ENCODER_RANGE_DN "36"
#define ENCODER_FMS_FRONT_UP "20"
#define ENCODER_FMS_FRONT_DN "21"
#define ENCODER_FMS_BACK_UP "18"
#define ENCODER_FMS_BACK_DN "19"
#define ENCODER_CRS_FRONT_UP "70"
#define ENCODER_CRS_FRONT_DN "71"
#define ENCODER_CRS_BACK_UP "68"
#define ENCODER_CRS_BACK_DN "69"
#define ENCODER_COM_FRONT_UP "65"
#define ENCODER_COM_FRONT_DN "66"
#define ENCODER_COM_BACK_UP "63"
#define ENCODER_COM_BACK_DN "64"
#define ENCODER_VOL_COM_UP "59"
#define ENCODER_VOL_COM_DN "60"

/**************************** Mux 1 Pins send values **********************************/
#define MUX_1_0 "13" // direct to
#define MUX_1_1 "6" // Soft Key 7
#define MUX_1_2 "7" // Soft Key 8
#define MUX_1_3 "8" // Soft Key 9
#define MUX_1_4 "9" // Soft Key 10
#define MUX_1_5 "10" // Soft Key 11
#define MUX_1_6 "11" // Soft Key 12
#define MUX_1_7 "0" // Soft Key 1
#define MUX_1_8 "1" // Soft Key 2
#define MUX_1_9 "2" // Soft Key 3
#define MUX_1_10 "3" // Soft Key 4
#define MUX_1_11 "4" // Soft Key 5
#define MUX_1_12 "5" // Soft Key 6
#define MUX_1_13 "" // n.c.
#define MUX_1_14 "" // n.c.
#define MUX_1_15 "" // n.c.

/**************************** Mux 2 Pins send values **********************************/
#define MUX_2_0 "27" // Nav Button
#define MUX_2_1 "26" // Alt Button
#define MUX_2_2 "25" // HDG Button
#define MUX_2_3 "24" // FD
#define MUX_2_4 "23" // AP
#define MUX_2_5 "34" // DN
#define MUX_2_6 "32" // FLC
#define MUX_2_7 "33" // UP
#define MUX_2_8 "31" // VS
#define MUX_2_9 "30" // BC
#define MUX_2_10 "29" // APR
#define MUX_2_11 "17" // ENT Button
#define MUX_2_12 "14" // CLR
#define MUX_2_13 "15" // PROC
#define MUX_2_14 "12" // FPL
#define MUX_2_15 "16" // MENU

/**************************** Mux 3 Pins send values **********************************/
#define MUX_3_0 "58" // Alt Push
#define MUX_3_1 "50" // NAV Push
#define MUX_3_2 "22" // FMS Push
#define MUX_3_3 "72" // CRS Baro Push
#define MUX_3_4 "67" // COM Push
#define MUX_3_5 "61" // VOL COM Push
#define MUX_3_6 "37" // Range Push
#define MUX_3_7 "53" // HDG Push
#define MUX_3_8 "44" // VOL NAV Push
#define MUX_3_9 "40" // Range Left	
#define MUX_3_10 "39" // Range Down
#define MUX_3_11 "41" // Range Right
#define MUX_3_12 "38" // Range Up
#define MUX_3_13 "62" // Coggle COM
#define MUX_3_14 "45" // Nav Switch
#define MUX_3_15 "28" // VNV

/****************************** ENCODERS *****************************************/

Encoder encoder_hdg(ENCODER_HDG_A,ENCODER_HDG_B);
Encoder encoder_range(ENCODER_RANGE_A,ENCODER_RANGE_B);
Encoder encoder_vol_com(ENCODER_VOL_COM_A,ENCODER_VOL_COM_A);

Encoder encoder_com_front(ENCODER_COM_FRONT_A, ENCODER_COM_FRONT_B);
Encoder encoder_com_back(ENCODER_COM_BACK_A, ENCODER_COM_BACK_B);

Encoder encoder_crs_front(ENCODER_CRS_FRONT_A, ENCODER_CRS_FRONT_B);
Encoder encoder_crs_back(ENCODER_CRS_BACK_A, ENCODER_CRS_BACK_B);

Encoder encoder_fms_front(ENCODER_FMS_FRONT_A, ENCODER_FMS_FRONT_B);
Encoder encoder_fms_back(ENCODER_FMS_BACK_A, ENCODER_FMS_BACK_B);

Encoder encoder_nav_front(ENCODER_NAV_FRONT_A, ENCODER_NAV_FRONT_B);
Encoder encoder_nav_back(ENCODER_NAV_BACK_A, ENCODER_NAV_BACK_B);

Encoder encoder_alt_front(ENCODER_ALT_FRONT_A, ENCODER_ALT_FRONT_B);
Encoder encoder_alt_back(ENCODER_ALT_BACK_A, ENCODER_ALT_BACK_B);

Encoder encoder_vol_nav(ENCODER_VOL_NAV_A,ENCODER_VOL_NAV_B);

/***********************************************************************/

#define MUX_BUTTONS_UPDATE_INTERVAL 50 // in milliseconds

/****************************** Variables *****************************************/
int32_t positionLeft  = -999;
int32_t positionRight = -999;

CD74HC4067 mux(MUX_S0, MUX_S1, MUX_S2, MUX_S3);

unsigned long nextKeysMillis=0;   // count millis for next Button updates
unsigned long currentMillis;    

void setup()
{
  // config mux
  pinMode(MUX_S0, OUTPUT);
  pinMode(MUX_S1, OUTPUT);
  pinMode(MUX_S2, OUTPUT);
  pinMode(MUX_S3, OUTPUT);
  pinMode(MUX1_INPUT, INPUT);
  pinMode(MUX2_INPUT, INPUT);
  pinMode(MUX3_INPUT, INPUT);


#if defined(DEBUG)
  Serial.begin(115200);
  Serial.println("Start Encoders:");
#endif

  // start I2c bus
  Wire.begin(); // join i2c bus (address optional for master)
  Wire.setClock(400000); // choose 400 kHz I2C rate

  // set all encodder to zero
  encoder_hdg.write(0);
  encoder_range.write(0);
  encoder_vol_com.write(0);
  encoder_com_front.write(0);
  encoder_com_back.write(0);
  encoder_crs_front.write(0);
  encoder_crs_back.write(0);
  encoder_fms_front.write(0);
  encoder_fms_back.write(0);
  encoder_nav_front.write(0);
  encoder_nav_back.write(0);
  encoder_alt_front.write(0);
  encoder_alt_back.write(0);
  encoder_vol_nav.write(0);

}

void loop()
{
  currentMillis = millis();  
  // read encoders and send data
  ReadEncoderAndSend(encoder_alt_front, ENCODER_ALT_FRONT_UP, ENCODER_ALT_FRONT_DN);
  ReadEncoderAndSend(encoder_alt_back, ENCODER_ALT_BACK_UP, ENCODER_ALT_BACK_DN);
  ReadEncoderAndSend(encoder_hdg, ENCODER_HDG_UP, ENCODER_HDG_DN);
  ReadEncoderAndSend(encoder_nav_front, ENCODER_NAV_FRONT_UP, ENCODER_NAV_FRONT_DN);
  ReadEncoderAndSend(encoder_nav_back, ENCODER_NAV_BACK_UP, ENCODER_NAV_BACK_DN);
  ReadEncoderAndSend(encoder_vol_nav,ENCODER_VOL_NAV_UP, ENCODER_VOL_NAV_DN);
  ReadEncoderAndSend(encoder_range, ENCODER_RANGE_UP, ENCODER_RANGE_DN);
  ReadEncoderAndSend(encoder_fms_front, ENCODER_FMS_FRONT_UP, ENCODER_FMS_FRONT_DN);
  ReadEncoderAndSend(encoder_fms_back, ENCODER_FMS_BACK_UP, ENCODER_FMS_BACK_DN);
  ReadEncoderAndSend(encoder_crs_front, ENCODER_CRS_FRONT_UP, ENCODER_CRS_FRONT_DN);
  ReadEncoderAndSend(encoder_crs_back, ENCODER_CRS_BACK_UP, ENCODER_CRS_BACK_UP);
  ReadEncoderAndSend(encoder_com_front, ENCODER_COM_FRONT_UP, ENCODER_COM_FRONT_DN);
  ReadEncoderAndSend(encoder_com_back, ENCODER_COM_BACK_UP, ENCODER_COM_BACK_DN);
  ReadEncoderAndSend(encoder_vol_com, ENCODER_VOL_COM_UP, ENCODER_VOL_COM_DN);


  if (currentMillis >= nextKeysMillis) {   
    for(uint8_t i=0,n=16;i<n;i++){
        // set channel
        mux.channel(i);
        // wait for channel switching (datasheet)
        delay(1);
        // read mux pins
        int mux1Pin=digitalRead(MUX1_INPUT);
        int mux2Pin=digitalRead(MUX2_INPUT);
        int mux3Pin=digitalRead(MUX3_INPUT);

        // mux 1
        if(mux1Pin==0) //is the button pressed?
        {
          ProcessMux1(i); // process values
          while(digitalRead(MUX1_INPUT)!=1) // wait until not pressed anymore
          {
            delay(1);
          }
        }

        // mux 2
        if(mux2Pin==0) //is the button pressed?
        {
          ProcessMux2(i); // process values
          while(digitalRead(MUX2_INPUT)!=1) // wait until not pressed anymore
          {
            delay(1);
          }          
        }

        // Mux 3
        if(mux3Pin==0) //is the button pressed?
        {
          ProcessMux3(i);// process values
          // better PAN movement
          if(i<=8 || i>=13){ // wait until not pressed anymore except pan buttons, we need repead there
            while(digitalRead(MUX3_INPUT)!=1) 
            {
              delay(1);
            }        
          }  
        } // if Mux3pin

        #if defined(DEBUG)
         Serial.print(mux1Pin);
         Serial.print(",");
         Serial.print(mux2Pin);
         Serial.print(",");
         Serial.print(mux3Pin);
         Serial.print(",");  
        #endif      
      } //for
      nextKeysMillis = currentMillis + MUX_BUTTONS_UPDATE_INTERVAL;  

      #if defined(DEBUG)
        Serial.println(""); 
      #endif
  }// millis
  #if defined(DEBUG)
   Serial.println("");
  #endif
} // Loop


/***************************************************************************
* Read the Encode rvalue and send the corresponding message to the ESP32
* depenting which direction is used.
****************************************************************************/
void ReadEncoderAndSend(Encoder &myEncoder, String msg_up, String msg_dn){
  int32_t iEncAltBack = myEncoder.read();
          
  if(iEncAltBack >2 || iEncAltBack <-2)
  {
    myEncoder.write(0);  
    if(iEncAltBack >0)
    {
      #if defined(DEBUG)
        Serial.println("encoder up");
      #endif
      I2CSend(msg_up);
    }else
    {
      #if defined(DEBUG)
        Serial.println("encoder down");
      #endif
      I2CSend(msg_dn);
    }

  }
} //ReadEncoderAndSend

/***************************************************************************
* Send data to ESP32
* It contains of key and value because the ESP32 can also use by Mobilfight
* In my case the Key is always '0'
****************************************************************************/
void I2CSend(String msg){
  Wire.beginTransmission(0x27); // transmit to device #4
  Wire.write('0'); // sends
  Wire.write(0x0D);
  Wire.write(msg.c_str());
  Wire.write(0x00);
  Wire.endTransmission(); // stop transmitting
} //I2CSend

/***************************************************************************
* Process mux 1 and send the corresponding value
****************************************************************************/
void ProcessMux1(int val)
{
  switch (val){
    case 0: 
      I2CSend(MUX_1_0);
      break;
    case 1: 
      I2CSend(MUX_1_1);
      break;
    case 2: 
      I2CSend(MUX_1_2);
      break;
    case 3:
      I2CSend(MUX_1_3);
      break;
    case 4:
      I2CSend(MUX_1_4);
      break;
    case 5:
      I2CSend(MUX_1_5);
      break;
    case 6: 
      I2CSend(MUX_1_6);
      break;
    case 7:
      I2CSend(MUX_1_7);
      break;
    case 8:
      I2CSend(MUX_1_8);
      break;
    case 9:
      I2CSend(MUX_1_9);
      break;
    case 10:
      I2CSend(MUX_1_10);
      break;
    case 11:
      I2CSend(MUX_1_11);
      break;
    case 12:
      I2CSend(MUX_1_12);
      break;
    case 13:
      break;
    case 14:
      break;
    case 15:
      break;                                                                                                                                                                                                    
  }
} //ProcessMux1

/***************************************************************************
* Process mux 2 and send the corresponding value
****************************************************************************/
void ProcessMux2(int val)
{
  switch (val){
    case 0: 
      I2CSend(MUX_2_0);
      break;
    case 1: 
      I2CSend(MUX_2_1);
      break;
    case 2: 
      I2CSend(MUX_2_2);
      break;
    case 3: 
      I2CSend(MUX_2_3);
      break;
    case 4: 
      I2CSend(MUX_2_4);
      break;
    case 5: 
      I2CSend(MUX_2_5);
      break;
    case 6: 
      I2CSend(MUX_2_6);
      break;
    case 7: 
      I2CSend(MUX_2_7);
      break;
    case 8: 
      I2CSend(MUX_2_8);
      break;
    case 9: 
      I2CSend(MUX_2_9);
      break;
    case 10: 
      I2CSend(MUX_2_10);
      break;
    case 11: 
      I2CSend(MUX_2_11);
      break;
    case 12: 
      I2CSend(MUX_2_12);
      break;
    case 13: 
      I2CSend(MUX_2_13);
      break;
    case 14: 
      I2CSend(MUX_2_14);
      break;
    case 15: 
      I2CSend(MUX_2_15);
      break;                                                                                                                                                                                                    
  }
} //ProcessMux2

/***************************************************************************
* Process mux 3 and send the corresponding value
****************************************************************************/
void ProcessMux3(int val)
{
  switch (val){
    case 0: 
      I2CSend(MUX_3_0);
      break;
    case 1: 
      I2CSend(MUX_3_1);
      break;
    case 2: 
      I2CSend(MUX_3_2);
      break;
    case 3: 
      I2CSend(MUX_3_3);
      break;
    case 4: 
      I2CSend(MUX_3_4);
      break;
    case 5: 
      I2CSend(MUX_3_5);
      break;
    case 6: 
      I2CSend(MUX_3_6);
      break;
    case 7: 
      I2CSend(MUX_3_7);
      break;
    case 8: 
      I2CSend(MUX_3_8);
      break;
    case 9: 
      I2CSend(MUX_3_9);
      break;
    case 10: 
      I2CSend(MUX_3_10);
      break;
    case 11:
      I2CSend(MUX_3_11);
      break;
    case 12:
      I2CSend(MUX_3_12);
      break;
    case 13: 
      I2CSend(MUX_3_13);
      break;
    case 14: 
      I2CSend(MUX_3_14);
      break;
    case 15: //VNV
      I2CSend(MUX_3_15);
      break;                                                                                                                                                                                                    
  }
} //ProcessMux3

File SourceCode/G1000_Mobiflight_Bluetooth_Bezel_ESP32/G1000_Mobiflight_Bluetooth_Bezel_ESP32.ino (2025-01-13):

#include "BleKeyboard.h"
#include <Wire.h>

// Address and communication for Mobiflight
#define I2C_MOBIFLIGHT_ADDR 0x27
#define I2C_MOBIFLIGHT_SDA 21
#define I2C_MOBIFLIGHT_SCL 22
#define MAX_LENGTH_MESSAGE          96 

#define END_OF_I2C_MESSAGE              0x00
#define END_OF_I2C_COMMAND              0x0D      // carriage return in ASCII
#define END_OF_I2C_PARTIAL_MESSAGE      0x0A      // line feed in ASCII

#define WAIT_KEY_PRESS 15 
#define WAIT_KEY_RELEASE 15 

//#define DEBUG
#define NODEBUG  


enum {
    NOT_SYNCHRONIZED = 0,
    RECEIVE_COMMAND,
    RECEIVE_DATA
};

int16_t _messageID = 0;
char _message[MAX_LENGTH_MESSAGE];

BleKeyboard bleKeyboard("G1000 PFD", "Gagagu" , 100);

void setup() {

#if defined(DEBUG)  
  Serial.begin(115200);
  Serial.setDebugOutput(false);
#endif

  // setup i2c receive callback
  Wire.onReceive(onReceive);

  // init i2c busses
  Wire.begin((uint8_t)I2C_MOBIFLIGHT_ADDR,I2C_MOBIFLIGHT_SDA,I2C_MOBIFLIGHT_SCL,400000);
  
  bleKeyboard.setDelay(5);
  bleKeyboard.begin();
  Serial.println("start");
}

void loop() {
  delay(30);
}

void onReceive(int received_bytes) {
//Serial.println("receive");
  static uint8_t byte_counter = 0;
  static uint8_t state = RECEIVE_COMMAND;
  char buffer[7] = {0};                                    // range is -32768 ... 32767 -> max. 6 character plus terminating NULL

  for (uint8_t i = 0; i < received_bytes; i++) {
    switch (state) {
      case NOT_SYNCHRONIZED:
        if (Wire.read() == END_OF_I2C_MESSAGE) {              // wait for end of message to get synchronized
          state = RECEIVE_COMMAND;
          byte_counter = 0;
        }
        break;

      case RECEIVE_COMMAND:
        buffer[i] = Wire.read();
       // Serial.print(buffer[i], HEX);
        if (buffer[i] == END_OF_I2C_COMMAND) {
          buffer[i] = 0x00;                                   // terminate string
          _messageID = atoi(buffer);
          state = RECEIVE_DATA;                               // next bytes are Data Bytes
        }
        if (i >= 6) {                                         // buffer overflow for messageID
          state = NOT_SYNCHRONIZED;                          // something went wrong, get a new synchronization
          byte_counter = 0;
          return;
        }
        break;

      case RECEIVE_DATA:
      //Serial.println("data");
        _message[byte_counter] = Wire.read();
        if (_message[byte_counter] == END_OF_I2C_MESSAGE) {    // end of message detected, prepare for receiving next messageID
          byte_counter = 0;
          state = RECEIVE_COMMAND;

          if(_messageID==0){ // we only await one command with value
            if(bleKeyboard.isConnected()) {
              handleCommand();
            }
          }
          return;
        } else if(_message[byte_counter] == END_OF_I2C_PARTIAL_MESSAGE) {   // end of partial message detected, next transmission will be rest of message  
          return;                                             // keep receiving data
        } else {
          byte_counter++;                                     // get the next byte
        }
        break;

      default:
        break;
    }
  }
  state = NOT_SYNCHRONIZED;                                 // We shouldn't come here, something went wrong
}


void handleCommand(){

  int command= atoi(_message);
#if defined(DEBUG)   
   Serial.print("command:");
   Serial.println(command);
#endif

  switch(command){
    case 0: // Soft Key 1
      bleKeyboard.press(KEY_LEFT_SHIFT);
      delay(WAIT_KEY_PRESS);
      bleKeyboard.press('1');
      delay(WAIT_KEY_RELEASE);
      bleKeyboard.releaseAll();        
      break;
    case 1: // Soft Key 2
      bleKeyboard.press(KEY_LEFT_SHIFT);
      delay(WAIT_KEY_PRESS);
      bleKeyboard.press('2');
      delay(WAIT_KEY_RELEASE);
      bleKeyboard.releaseAll(); 
      break;
    case 2: // Soft Key 3
      bleKeyboard.press(KEY_LEFT_SHIFT);
      delay(WAIT_KEY_PRESS);
      bleKeyboard.press('3');
      delay(WAIT_KEY_RELEASE);
      bleKeyboard.releaseAll(); 
      break;
    case 3: // Soft Key 4
      bleKeyboard.press(KEY_LEFT_SHIFT);
      delay(WAIT_KEY_PRESS);
      bleKeyboard.press('4');
      delay(WAIT_KEY_RELEASE);
      bleKeyboard.releaseAll(); 
      break;
    case 4: // Soft Key 5
      bleKeyboard.press(KEY_LEFT_SHIFT);
      delay(WAIT_KEY_PRESS);
      bleKeyboard.press('5');
      delay(WAIT_KEY_RELEASE);
      bleKeyboard.releaseAll(); 
      break;
    case 5: // Soft Key 6
      bleKeyboard.press(KEY_LEFT_SHIFT);
      delay(WAIT_KEY_PRESS);
      bleKeyboard.press('6');
      delay(WAIT_KEY_RELEASE);
      bleKeyboard.releaseAll(); 
      break;
    case 6: // Soft Key 7
      bleKeyboard.press(KEY_LEFT_SHIFT);
      delay(WAIT_KEY_PRESS);
      bleKeyboard.press('7');
      delay(WAIT_KEY_RELEASE);
      bleKeyboard.releaseAll(); 
      break;
    case 7: // Soft Key 8
      bleKeyboard.press(KEY_LEFT_SHIFT);
      delay(WAIT_KEY_PRESS);
      bleKeyboard.press('8');
      delay(WAIT_KEY_RELEASE);
      bleKeyboard.releaseAll(); 
      break;
    case 8: // Soft Key 9
      bleKeyboard.press(KEY_LEFT_SHIFT);
      delay(WAIT_KEY_PRESS);
      bleKeyboard.press('9');
      delay(WAIT_KEY_RELEASE);
      bleKeyboard.releaseAll(); 
      break;
    case 9: // Soft Key 10
      bleKeyboard.press(KEY_LEFT_SHIFT);
      delay(WAIT_KEY_PRESS);
      bleKeyboard.press('0');
      delay(WAIT_KEY_RELEASE);
      bleKeyboard.releaseAll(); 
      break;
    case 10: // Soft Key 11
      bleKeyboard.press(KEY_LEFT_SHIFT);
      delay(WAIT_KEY_PRESS);
      bleKeyboard.press(KEY_NUM_MINUS);
      delay(WAIT_KEY_RELEASE);
      bleKeyboard.releaseAll(); 
      break;
    case 11: // Soft Key 12
      bleKeyboard.press(KEY_LEFT_SHIFT);
      delay(WAIT_KEY_PRESS);
      bleKeyboard.press('=');
      delay(WAIT_KEY_RELEASE);
      bleKeyboard.releaseAll(); 
      break;
    case 12: // FPL
      bleKeyboard.press('f');
      delay(WAIT_KEY_RELEASE);
      bleKeyboard.releaseAll(); 
      break;
    case 13: //DIR-TO
      bleKeyboard.press('d');
      delay(WAIT_KEY_RELEASE);
      bleKeyboard.releaseAll(); 
      break;
    case 14: // CLR
      bleKeyboard.press('`');
      delay(WAIT_KEY_RELEASE);
      bleKeyboard.releaseAll();       
      break;
    case 15: // PROC
      bleKeyboard.press('p');
      delay(WAIT_KEY_RELEASE);
      bleKeyboard.releaseAll(); 
      break;
    case 16: // MENU
      bleKeyboard.press('m');
      delay(WAIT_KEY_RELEASE);
      bleKeyboard.releaseAll(); 
      break;
    case 17: // ENT
      bleKeyboard.write(KEY_RETURN);
      break;
    case 18: // Big FMS Knob+
      bleKeyboard.write(KEY_DOWN_ARROW);
      break;
    case 19: // Big FMS Knob-
      bleKeyboard.write(KEY_UP_ARROW);
      break;
    case 20: // Small FMS Knob+
      bleKeyboard.write(KEY_RIGHT_ARROW);
      break;
    case 21: // Small FMS Knob-
      bleKeyboard.write(KEY_LEFT_ARROW);
      break;
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
